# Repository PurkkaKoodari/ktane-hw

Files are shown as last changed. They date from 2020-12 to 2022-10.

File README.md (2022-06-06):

# KTaNE HW

This project is a hardware reimplementation of the game [Keep Talking and Nobody Explodes][ktane]. The game runs fully on the physical device and is controlled using a web interface over Wi-Fi. The project will be documented in this repository &ndash; expect the links below to be broken for the near future.

(TODO: insert photos here)

## Architecture

The hardware is built around a Raspberry Pi Zero W, which runs the main controller software, attached to a [backplane](doc/hardware/backplane.md) that provides power, connectivity and audio. The game's [modules](doc/hardware/modules.md) are built as independent devices, usually based on an Arduino Nano, which connect to the backplane using RJ-45 connectors (with a completely nonstandard usage of the pins).

The software can be divided into three parts: the [main controller](doc/software/main_controller.md), written in Python 3 using `asyncio` and [`websockets`][websockets]; the module software, written in C++ and built using [`arduino-cli`][arduino-cli]; and the Web interface, written using [Preact][preact]. In addition, one can run a [room server](doc/software/room_server.md), which supports room-scale audio and DMX lights and other effects.

## License

Unless otherwise noted, all software in this repository is licensed under the [MIT license](LICENSE); the hardware design files in `hardware/` are licensed under the [CERN-OHL-P v2](hardware/LICENSE); and the sounds in `sounds/` are licensed under CC-BY 3.0 (see [sounds/CREDITS.txt](sounds/CREDITS.txt) for authors).

This project is not in any way related to or endorsed by Steel Crate Games, nor does it include any assets from the original game. If you intend to build a copy of the project, please support them and [purchase a copy of the game][buy-ktane]!

[ktane]: http://www.keeptalkinggame.com/
[buy-ktane]: https://keeptalkinggame.com/#buynow
[websockets]: https://websockets.readthedocs.io/en/stable/intro.html
[arduino-cli]: https://arduino.github.io/arduino-cli/latest/commands/arduino-cli/
[preact]: https://preactjs.com/

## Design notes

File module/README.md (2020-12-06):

# Module firmware

## Libraries

- [Arduino-MCP2515][mcp2515] for CAN communication
- [Adafruit_LED_Backpack][ledbackpack] for modules using the HT16K33 chip
- [Custom library][ht1632c_bitbang] for modules using the HT1632C chip (see the [README.md][ht1632c_readme])
- [LiquidCrystal_I2C][lcd_i2c] for modules using 1602 LCDs with a PCF8574
- [FastLED][fastled] for modules using WS2812B (NeoPixel) LEDs

## Building

Building from command line using the included script is highly recommended.

Install [arduino-cli] first, then run `python3 build.py`.

Substitute your module details and serial port name.
Refer to `python3 build.py --help` for other options.

```sh
python3 build.py <module> <hwver> <serial> -u /dev/<serialport>
```

[arduino-cli]: https://arduino.github.io/arduino-cli/latest/installation/
[mcp2515]: https://github.com/autowp/arduino-mcp2515
[ht1632c_bitbang]: ../arduino-libraries/ht1632c_bitbang
[ht1632c_readme]: ../arduino-libraries/ht1632c_bitbang/README.md
[ledbackpack]: https://github.com/adafruit/Adafruit_LED_Backpack/
[lcd_i2c]: https://github.com/johnrickman/LiquidCrystal_I2C
[fastled]: https://github.com/FastLED/FastLED

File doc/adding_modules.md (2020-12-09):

# Adding modules

This document provides a step-by-step guide to adding new modules to the system.

## Conventions

### Version numbering

Each module has two version numbers, the hardware and software version, each represented as `major.minor`.

- The first released version is always 1.0.
- **Hardware version:**
    - The hardware version should always match the one printed on the board's silkscreen.
    - Any pre-release hardware should be marked as version 1.0 so that it can become the 1.0 release when it works.
    - A **major** version change indicates a major redesign that requires large firmware changes (e.g. changing of full mechanism).
    - A **minor** change may be anything smaller. It may still require changes in the firmware or main controller actions (e.g. pin changes, changing a driver chip, fixing errors that needed workarounds) or it may be a non-functional board update.
- **Software version:**
    - The software version is not tied to the hardware version, but relates to the bus protocol versioning.
    - Pre-release software may opt to use version 0.x or 1.0.
    - A **major** version change indicates that the main controller software will need a explicit update to support the protocol used by this version.
    - A **minor** version change indicates that the main controller may support this version without an explicit update. It may still be unable to use some new features in this version.

### Module IDs

You'll need a unique module ID. IDs 1-63 are reserved for vanilla modules, IDs 64-4095 for modded modules. Choose the lowest free ID from the appropriate range and add it in `bus_protocol.md`.

## 1. Build the hardware

A module starts with hardware. Most modules consist of the following:

- Faceplate, 100mm x 110mm x 3mm (WxHxD), acrylic/aluminum
    - 5mm on top/bottom reserved for mounting
    - All measurements below are from the 100mm x 100mm area excluding the mounting part
- PCB, usually 100mm x 100mm
    - 100mm x 100mm chosen for easy & cheap production
- Arduino-compatible microprocessor
    - Current modules use an Arduino Nano (or clone) on headers
- MCP2515 based CAN module with 5V bus voltage
    - Current modules use a MCP2515+TJA1050 module on headers, commonly available from China
- 10mm RGB LED for non-needy modules, centered 8mm from the right and top edges
- Mounting holes with M3 bolts
    - Usually centered 5mm from each edge, can be customized depending on module
    - With the RGB LED, the standard location for the top-right hole is 20mm from the right edge
- Various electrical, 3D-printed, laser-cut, etc. parts for the user interface

(TODO: add CAD models to repository for reference)

Before designing a new PCB, see if the [base module PCB][base-pcb] is enough for your needs. It breaks out many pins of the Arduino, including PWM and I&sup2;C and adds pins for two common LED matrix drivers, the HT1632C and HT16K33. It can be used as-is or by adding an adapter board. If you decide you need your own board, the base PCB is a good starting point as well.

Most module electronics should work with 5V. The MODULE_READY and MODULE_ENABLE signals, as well as the CAN bus, are configured for 5V operation. If your components need 3.3V, the module will need its own regulator.

The module connector additionally provides a 12V pin that can be used for more power-hungry peripherals such as motors or solenoids. This pin is not strictly 12V, but is intended to be the unregulated battery voltage &mdash; it may be anything from 11V to 15V, so make sure your components can handle that. Some bomb casings may not provide 12V power at all, as most modules don't use it.

## 2. Build the module firmware

The Arduino-based firmware needs to be extended to support your module.

1. Add your module ID to the start of `module.h`. This is the only change you'll need to make to existing files.
2. Copy [`newmodule.h`][newmodule.h] and [`newmodule.cpp`][newmodule.cpp] to the `module` directory and write your code as described in the comments.
3. Follow the instructions in [`module/README.md`][module-readme] to configure your build.

## 3. Add support in the controller software

The main controller then needs to be extended.

1. Copy [`template.py`][template.py] to your module's name (in lowercase) and write your code as described in the comments.
2. Add the name of your module to `bombgame/modules/__init__.py` so it will be loaded properly.
3. Optionally, write tests for your module. <!-- TODO: create a standard location - probably bombgame/test/modules -->

## 4. Add support in the frontend

The frontend is going to be rewritten soon, instructions will be updated later.

[base-pcb]: ../hardware/module_base
[newmodule.h]: ../module/module_template/newmodule.h
[newmodule.cpp]: ../module/module_template/newmodule.cpp
[template.py]: ../maincontroller/bombgame/modules/template.py
[module-readme]: ../module/README.md

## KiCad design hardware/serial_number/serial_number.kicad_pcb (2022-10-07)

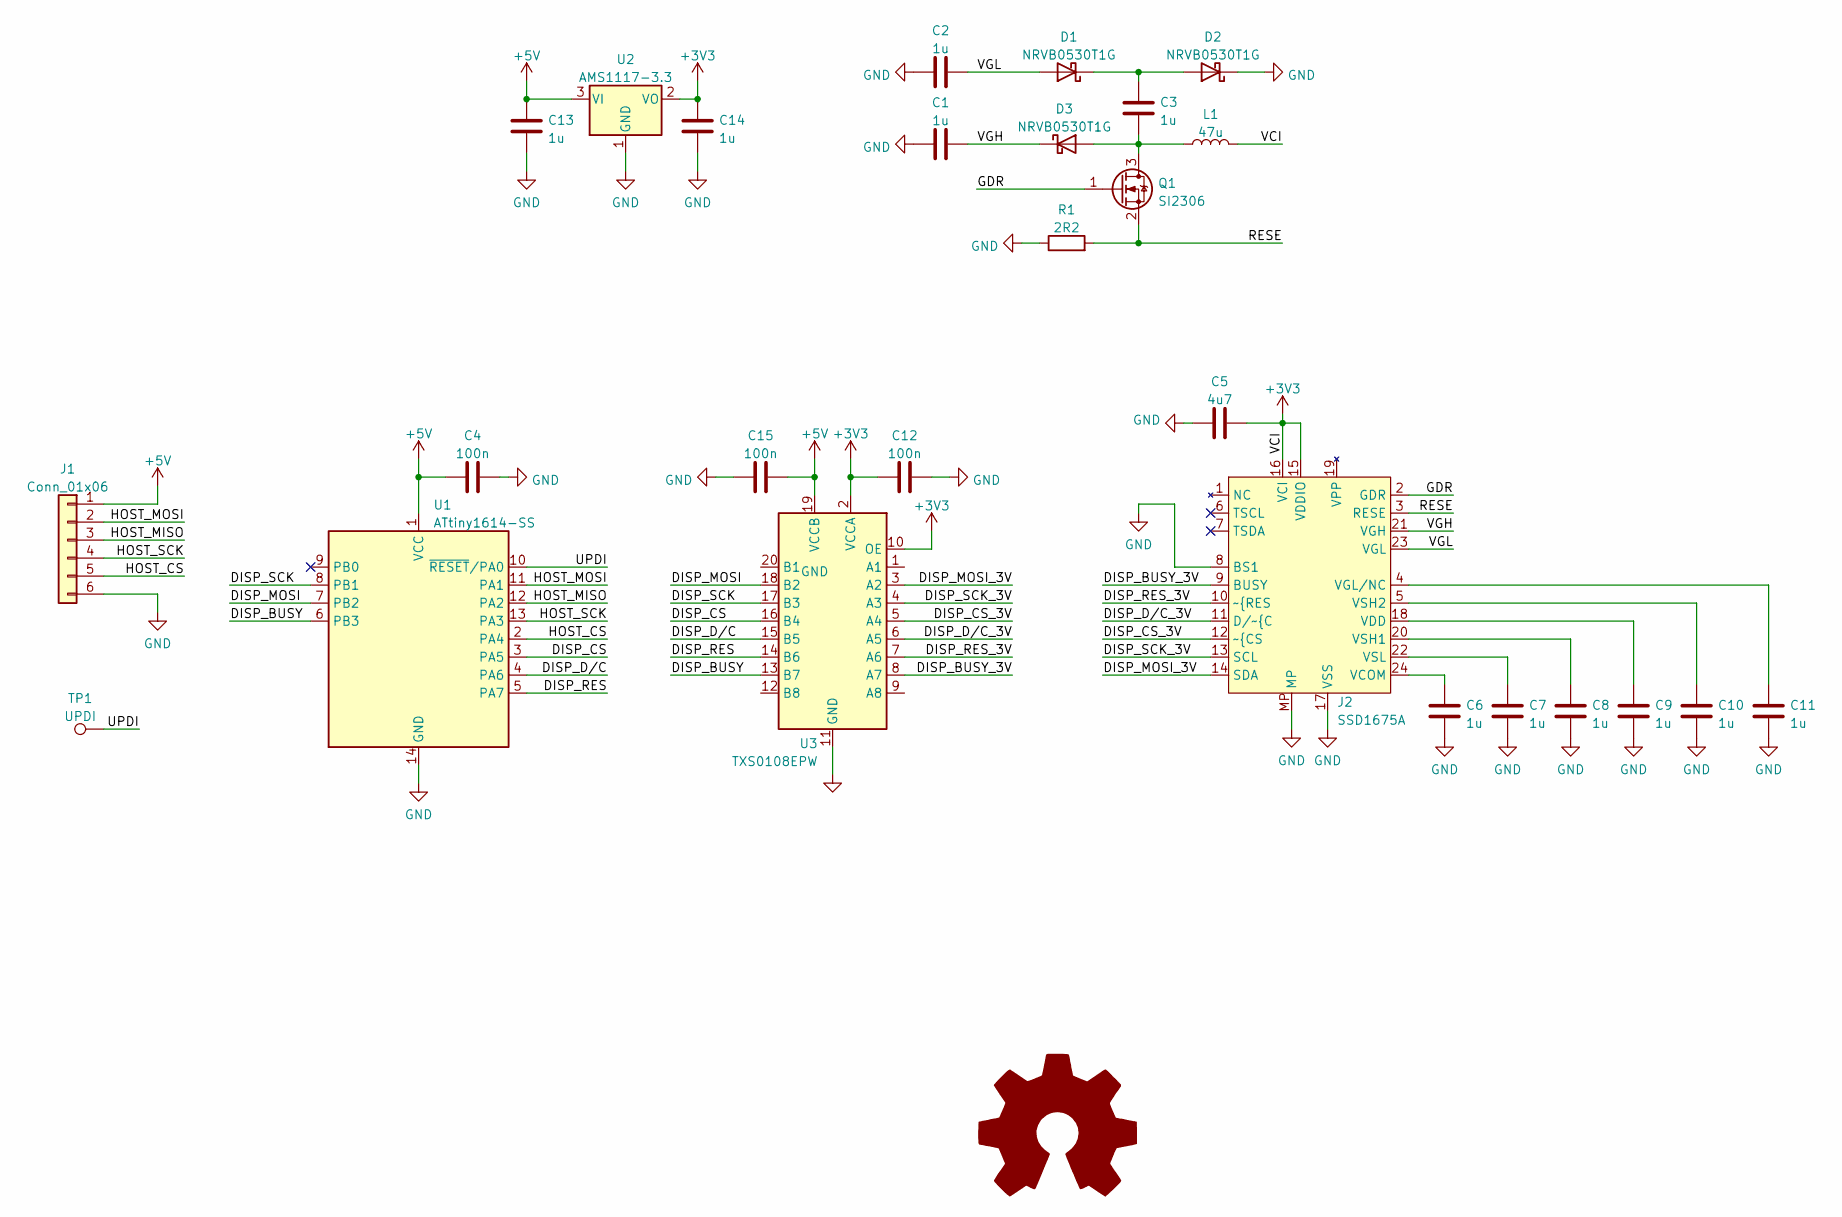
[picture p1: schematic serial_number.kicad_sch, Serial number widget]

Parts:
C1, C2, C3, C6, C7, C8, C9, C10, C11, C13, C14: 1u; C_0603_1608Metric_Pad1.08x0.95mm
C4, C12, C15: 100n; C_0603_1608Metric_Pad1.08x0.95mm
C5: 4u7; C_0603_1608Metric_Pad1.08x0.95mm
D1, D2, D3: NRVB0530T1G; D_SOD-123
J1: Conn_01x06; PinHeader_1x06_P2.54mm_Vertical
J2: SSD1675A; ER-CON24HT-1
L1: 47u; L_Taiyo-Yuden_NR-40xx
LOGO1: Logo_Open_Hardware_Large; OSHW-Logo_11.4x12mm_SilkScreen
Q1: SI2306; SOT-23_Handsoldering
R1: 2R2; R_0805_2012Metric_Pad1.20x1.40mm
TP1: UPDI; TestPoint_Pad_D2.5mm
U1: ATtiny1614-SS; SOIC-14_3.9x8.7mm_P1.27mm
U2: AMS1117-3.3; SOT-223-3_TabPin2
U3: TXS0108EPW; TSSOP-20_4.4x6.5mm_P0.65mm

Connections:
+3V3: C5.2, C12.1, C14.2, J2.15 (VDDIO), J2.16 (VCI), L1.2, U2.2 (VO), U3.2 (VCCA), U3.10 (OE)
+5V: C4.1, C13.2, C15.1, J1.1, U1.1 (VCC), U2.3 (VI), U3.19 (VCCB)
/DISP_BUSY: U1.6 (PB3), U3.13 (B7)
/DISP_BUSY_3V: J2.9 (BUSY), U3.8 (A7)
/DISP_CS: U1.3 (PA5), U3.16 (B4)
/DISP_CS_3V: J2.12 (~{CS), U3.5 (A4)
/DISP_D/C: U1.4 (PA6), U3.15 (B5)
/DISP_D/C_3V: J2.11 (D/~{C), U3.6 (A5)
/DISP_MOSI: U1.7 (PB2), U3.18 (B2)
/DISP_MOSI_3V: J2.14 (SDA), U3.3 (A2)
/DISP_RES: U1.5 (PA7), U3.14 (B6)
/DISP_RES_3V: J2.10 (~{RES), U3.7 (A6)
/DISP_SCK: U1.8 (PB1), U3.17 (B3)
/DISP_SCK_3V: J2.13 (SCL), U3.4 (A3)
/GDR: J2.2 (GDR), Q1.1 (G)
/HOST_CS: J1.5, U1.2 (PA4)
/HOST_MISO: J1.3, U1.12 (PA2)
/HOST_MOSI: J1.2, U1.11 (PA1)
/HOST_SCK: J1.4, U1.13 (PA3)
/RESE: J2.3 (RESE), Q1.2 (S), R1.2
/UPDI: TP1.1, U1.10 (~RESET/PA0)
/VGH: C1.2, D3.1 (K), J2.21 (VGH)
/VGL: C2.2, D1.2 (A), J2.23 (VGL)
GND: C1.1, C2.1, C4.2, C5.1, C6.1, C7.1, C8.1, C9.1, C10.1, C11.1, C12.2, C13.1, C14.1, C15.2, D2.1 (K), J1.6, J2.8 (BS1), J2.17 (VSS), J2.MP, R1.1, U1.14 (GND), U2.1 (GND), U3.11 (GND)
unnamed: C3.1, D1.1 (K), D2.2 (A)
unnamed: C3.2, D3.2 (A), L1.1, Q1.3 (D)
unnamed: C6.2, J2.24 (VCOM)
unnamed: C7.2, J2.22 (VSL)
unnamed: C8.2, J2.20 (VSH1)
unnamed: C9.2, J2.18 (VDD)
unnamed: C10.2, J2.5 (VSH2)
unnamed: C11.2, J2.4 (VGL/NC)

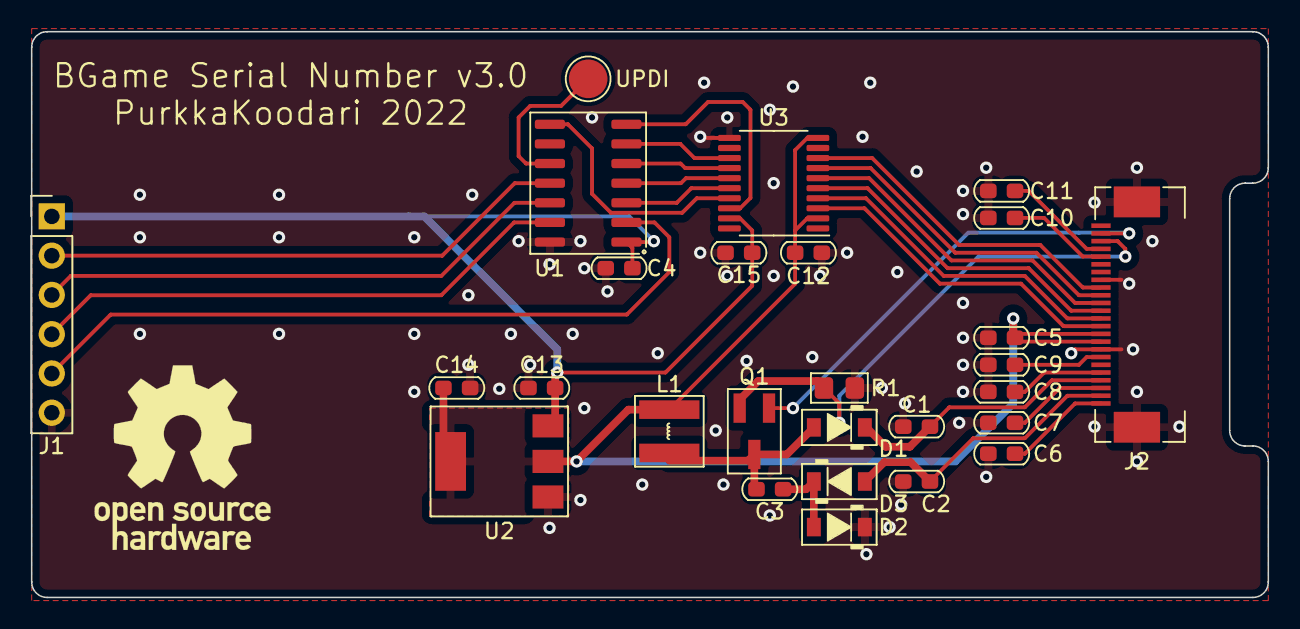
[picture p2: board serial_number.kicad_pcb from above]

Board: 2 copper layers, 80.0 x 36.6 mm, 28 parts (0 on the bottom side), 32 nets.

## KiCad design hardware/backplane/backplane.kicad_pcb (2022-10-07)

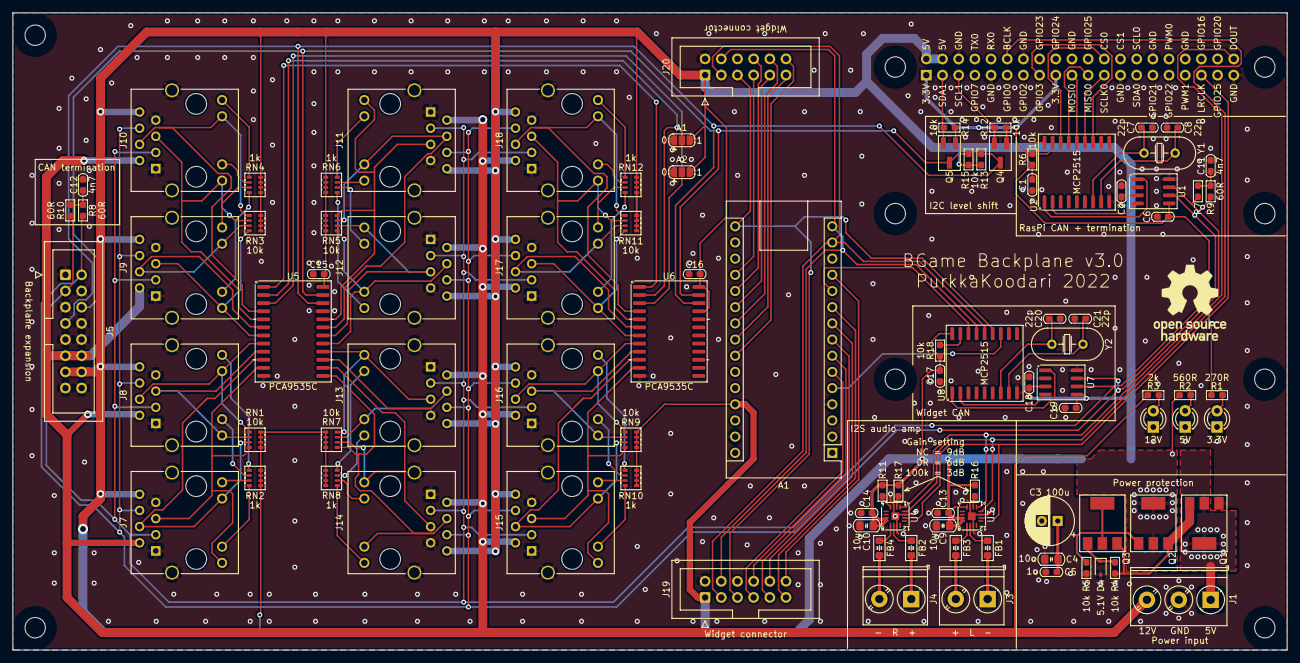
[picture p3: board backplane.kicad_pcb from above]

Board: 2 copper layers, 200.0 x 100.0 mm, 103 parts (1 on the bottom side), 116 nets.

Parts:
A1: Arduino_Nano_v3.x; Arduino_Nano
C1, C2, C6, C13, C14, C15, C16, C17, C18, C19: 100n; C_0603_1608Metric_Pad1.08x0.95mm
C3: 100u; CP_Radial_D7.5mm_P2.50mm
C4, C9, C10: 10u; C_0805_2012Metric_Pad1.18x1.45mm
C5: 1u; C_0603_1608Metric_Pad1.08x0.95mm
C7, C8, C20, C21: 22p; C_0603_1608Metric_Pad1.08x0.95mm
C11, C12: 4n7; C_0603_1608Metric_Pad1.08x0.95mm
D1, D2, D3: LED; LED_D3.0mm
D4: BZX384-5V1; D_SOD-323
FB1, FB2, FB3, FB4: Ferrite_Bead; Ferrite_0805_2012Metric_Pad1.05x1.20mm_BigPads
H_RPI1, H_RPI2: RPi_HDR; MountingHole_3.2mm_M3
H_RPI3, H_RPI4: RPi_ZERO; MountingHole_3.2mm_M3
H_RPI5, H_RPI6: RPi_3; MountingHole_3.2mm_M3
J1: Screw_Terminal_01x03; TerminalBlock_Phoenix_PT-1,5-3-5.0-H_1x03_P5.00mm_Horizontal
J2: Raspberry_Pi_2_3; PinSocket_2x20_P2.54mm_Vertical
J3, J4: Screw_Terminal_01x02; TerminalBlock_Phoenix_PT-1,5-2-5.0-H_1x02_P5.00mm_Horizontal
J5: Conn_02x08_Odd_Even; IDC-Header_2x08_P2.54mm_Vertical
J7, J8, J9, J10, J11, J12, J13, J14, J15, J16, J17, J18: RJ45_LED_Shielded; RJ45_RCH5242CB
J19, J20: Conn_02x06_Odd_Even; IDC-Header_2x06_P2.54mm_Vertical
JP1: GPIO_A1; SolderJumper-3_P1.3mm_Open_RoundedPad1.0x1.5mm
JP2: GPIO_A2; SolderJumper-3_P1.3mm_Open_RoundedPad1.0x1.5mm
LOGO1: Logo_Open_Hardware_Small; OSHW-Logo_11.4x12mm_SilkScreen
Q1, Q2, Q3: ZXMP4A16G; SOT-223-3_TabPin2
Q4, Q5: Q_NMOS_GSD; SOT-23_Handsoldering
R1: 270R; R_0603_1608Metric_Pad1.05x0.95mm
R2: 560R; R_0603_1608Metric_Pad1.05x0.95mm
R3: 2k; R_0603_1608Metric_Pad1.05x0.95mm
R4, R5, R6, R12, R13, R14, R15, R18: 10k; R_0603_1608Metric_Pad1.05x0.95mm
R7, R8, R9, R10: 60R; R_0603_1608Metric_Pad1.05x0.95mm
R11: 330k; R_0603_1608Metric_Pad1.05x0.95mm
R16, R17: 100k; R_0603_1608Metric_Pad1.05x0.95mm
RN1, RN3, RN5, RN7, RN9, RN11: 10k; R_Array_Convex_4x0603
RN2, RN4, RN6, RN8, RN10, RN12: 1k; R_Array_Convex_4x0603
U1, U7: TJA1051T/3; SOIC-8_3.9x4.9mm_P1.27mm
U2, U8: MCP2515-xSO; SOIC-18W_7.5x11.6mm_P1.27mm
U3, U4: MAX98357AETE; TQFN-16-1EP_3x3mm_P0.5mm_EP1.23x1.23mm
U5, U6: PCA9535C; SOIC-24W_7.5x15.4mm_P1.27mm
Y1, Y2: 8MHz; Crystal_HC49-U_Vertical

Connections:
+3V3: C1.1, C6.1, J2.1 (3V3), J2.17 (3V3), Q4.1 (G), Q5.1 (G), R1.1, R6.1, R12.1, R14.1, U1.5 (VIO), U2.18 (VDD)
+5V: J1.1, Q1.2 (D)
+12V: J1.3, J5.11, J5.12, J7.2, J8.2, J9.2, J10.2, J11.2, J12.2, J13.2, J14.2, J15.2, J16.2, J17.2, J18.2, R3.1
/CAN_CS: J2.24 (~CE0/GPIO8), U2.16 (~CS)
/CAN_INT: J2.15 (GPIO22), U2.12 (~INT)
/GPIO_ADDR1: JP1.2 (C), U5.2 (A1), U6.2 (A1)
/GPIO_ADDR2: JP2.2 (C), U5.3 (A2), U6.3 (A2)
/GPIO_INT: U5.1 (~INT), U6.1 (~INT)
/MISO_3V3: J2.21 (MISO0/GPIO9), U2.15 (SO)
/MODULE_LOCATE_0: J7.4, J7.11, RN1.7 (R2.2), U5.10 (IO0_6)
/MODULE_LOCATE_1: J8.4, J8.11, RN1.5 (R4.2), U5.8 (IO0_4)
/MODULE_LOCATE_2: J9.4, J9.11, RN3.7 (R2.2), U5.6 (IO0_2)
/MODULE_LOCATE_3: J10.4, J10.11, RN3.5 (R4.2), U5.4 (IO0_0)
/MODULE_LOCATE_4: J11.4, J11.11, RN5.7 (R2.2), U5.19 (IO1_6)
/MODULE_LOCATE_5: J12.4, J12.11, RN5.5 (R4.2), U5.17 (IO1_4)
/MODULE_LOCATE_6: J13.4, J13.11, RN7.7 (R2.2), U5.15 (IO1_2)
/MODULE_LOCATE_7: J14.4, J14.11, RN7.5 (R4.2), U5.13 (IO1_0)
/MODULE_LOCATE_8: J15.4, J15.11, RN9.7 (R2.2), U6.10 (IO0_6)
/MODULE_LOCATE_9: J16.4, J16.11, RN9.5 (R4.2), U6.8 (IO0_4)
/MODULE_LOCATE_10: J17.4, J17.11, RN11.7 (R2.2), U6.6 (IO0_2)
/MODULE_LOCATE_11: J18.4, J18.11, RN11.5 (R4.2), U6.4 (IO0_0)
/MODULE_SENSE_0: J7.5, J7.9, RN1.8 (R1.2), U5.11 (IO0_7)
/MODULE_SENSE_1: J8.5, J8.9, RN1.6 (R3.2), U5.9 (IO0_5)
/MODULE_SENSE_2: J9.5, J9.9, RN3.8 (R1.2), U5.7 (IO0_3)
/MODULE_SENSE_3: J10.5, J10.9, RN3.6 (R3.2), U5.5 (IO0_1)
/MODULE_SENSE_4: J11.5, J11.9, RN5.8 (R1.2), U5.20 (IO1_7)
/MODULE_SENSE_5: J12.5, J12.9, RN5.6 (R3.2), U5.18 (IO1_5)
/MODULE_SENSE_6: J13.5, J13.9, RN7.8 (R1.2), U5.16 (IO1_3)
/MODULE_SENSE_7: J14.5, J14.9, RN7.6 (R3.2), U5.14 (IO1_1)
/MODULE_SENSE_8: J15.5, J15.9, RN9.8 (R1.2), U6.11 (IO0_7)
/MODULE_SENSE_9: J16.5, J16.9, RN9.6 (R3.2), U6.9 (IO0_5)
/MODULE_SENSE_10: J17.5, J17.9, RN11.8 (R1.2), U6.7 (IO0_3)
/MODULE_SENSE_11: J18.5, J18.9, RN11.6 (R3.2), U6.5 (IO0_1)
/MOSI_3V3: J2.19 (MOSI0/GPIO10), U2.14 (SI)
/PCM_BCLK: J2.12 (GPIO18/PWM0), U3.16 (BCLK), U4.16 (BCLK)
/PCM_DOUT: J2.40 (GPIO21/SCLK1), U3.1 (DIN), U4.1 (DIN)
/PCM_LRCLK: J2.35 (GPIO19/MISO1), U3.14 (LRCLK), U4.14 (LRCLK)
/SCL: J5.7, Q4.3 (D), R13.2, U5.22 (SCL), U6.22 (SCL)
/SCLK_3V3: J2.23 (SCLK0/GPIO11), U2.13 (SCK)
/SCL_3V3: J2.5 (SCL/GPIO3), Q4.2 (S), R12.2
/SDA: J5.6, Q5.3 (D), R15.2, U5.23 (SDA), U6.23 (SDA)
/SDA_3V3: J2.3 (SDA/GPIO2), Q5.2 (S), R14.2
/SPKR_L+: FB3.2, J3.2
/SPKR_L-: FB1.2, J3.1
/SPKR_R+: FB4.2, J4.2
/SPKR_R-: FB2.2, J4.1
/WIDGET_CAN_CS: A1.11 (D8), U8.16 (~CS)
/WIDGET_CAN_INT: A1.5 (D2), U8.12 (~INT)
/WIDGET_CS0: A1.6 (D3), J19.7
/WIDGET_CS1: A1.7 (D4), J19.8
/WIDGET_CS2: A1.8 (D5), J19.9
/WIDGET_CS3: A1.9 (D6), J19.10
/WIDGET_CS4: A1.10 (D7), J19.11
/WIDGET_CS5: A1.12 (D9), J19.12
/WIDGET_CS6: A1.19 (A0), J20.7
/WIDGET_CS7: A1.20 (A1), J20.8
/WIDGET_CS8: A1.21 (A2), J20.9
/WIDGET_CS9: A1.22 (A3), J20.10
/WIDGET_CS10: A1.23 (A4), J20.11
/WIDGET_CS11: A1.24 (A5), J20.12
/WIDGET_MISO: A1.15 (D12), J19.4, J20.4, U8.15 (SO)
/WIDGET_MOSI: A1.14 (D11), J19.3, J20.3, U8.14 (SI)
/WIDGET_SCLK: A1.16 (D13), J19.5, J20.5, U8.13 (SCK)
CAN_H: J5.2, J7.6, J8.6, J9.6, J10.6, J11.6, J12.6, J13.6, J14.6, J15.6, J16.6, J17.6, J18.6, R7.1, R8.1, U1.7 (CANH), U7.7 (CANH)
CAN_L: J5.3, J7.3, J8.3, J9.3, J10.3, J11.3, J12.3, J13.3, J14.3, J15.3, J16.3, J17.3, J18.3, R9.1, R10.1, U1.6 (CANL), U7.6 (CANL)
GND: A1.4 (GND), A1.29 (GND), C1.2, C2.2, C3.2, C4.2, C5.2, C6.2, C7.2, C8.2, C9.1, C10.1, C11.2, C12.2, C13.1, C14.1, C15.2, C16.2, C17.2, C18.2, C19.2, C20.2, C21.2, D1.1 (K), D2.1 (K), D3.1 (K), D4.2 (A), J1.2, J2.6 (GND), J2.9 (GND), J2.14 (GND), J2.20 (GND), J2.25 (GND), J2.30 (GND), J2.34 (GND), J2.39 (GND), J5.1, J5.4, J5.5, J5.8, J5.9, J5.10, J5.15, J5.16, J7.1, J7.7, J7.SH, J8.1, J8.7, J8.SH, J9.1, J9.7, J9.SH, J10.1, J10.7, J10.SH, J11.1, J11.7, J11.SH, J12.1, J12.7, J12.SH, J13.1, J13.7, J13.SH, J14.1, J14.7, J14.SH, J15.1, J15.7, J15.SH, J16.1, J16.7, J16.SH, J17.1, J17.7, J17.SH, J18.1, J18.7, J18.SH, J19.2, J20.2, JP1.1 (A), JP2.1 (A), Q1.1 (G), R5.2, U1.2 (GND), U1.8 (S), U2.9 (VSS), U3.3 (GND), U3.11 (GND), U3.15 (GND), U3.17 (EP), U4.3 (GND), U4.11 (GND), U4.15 (GND), U4.17 (EP), U5.12 (VSS), U5.21 (A0), U6.12 (VSS), U7.2 (GND), U7.8 (S), U8.9 (VSS)
unnamed: C7.1, U2.7 (OSC2), Y1.1
unnamed: C8.1, U2.8 (OSC1), Y1.2
unnamed: C11.1, R7.2, R9.2
unnamed: C12.1, R8.2, R10.2
unnamed: C20.1, U8.7 (OSC2), Y2.1
unnamed: C21.1, U8.8 (OSC1), Y2.2
unnamed: D1.2 (A), R1.2
unnamed: D2.2 (A), R2.2
unnamed: D3.2 (A), R3.2
unnamed: D4.1 (K), Q3.1 (G), R4.2
unnamed: FB1.1, U3.10 (OUTN)
unnamed: FB2.1, U4.10 (OUTN)
unnamed: FB3.1, U3.9 (OUTP)
unnamed: FB4.1, U4.9 (OUTP)
unnamed: J7.10, RN2.8 (R1.2)
unnamed: J7.12, RN2.7 (R2.2)
unnamed: J8.10, RN2.6 (R3.2)
unnamed: J8.12, RN2.5 (R4.2)
unnamed: J9.10, RN4.8 (R1.2)
unnamed: J9.12, RN4.7 (R2.2)
unnamed: J10.10, RN4.6 (R3.2)
unnamed: J10.12, RN4.5 (R4.2)
unnamed: J11.10, RN6.8 (R1.2)
unnamed: J11.12, RN6.7 (R2.2)
unnamed: J12.10, RN6.6 (R3.2)
unnamed: J12.12, RN6.5 (R4.2)
unnamed: J13.10, RN8.8 (R1.2)
unnamed: J13.12, RN8.7 (R2.2)
unnamed: J14.10, RN8.6 (R3.2)
unnamed: J14.12, RN8.5 (R4.2)
unnamed: J15.10, RN10.8 (R1.2)
unnamed: J15.12, RN10.7 (R2.2)
unnamed: J16.10, RN10.6 (R3.2)
unnamed: J16.12, RN10.5 (R4.2)
unnamed: J17.10, RN12.8 (R1.2)
unnamed: J17.12, RN12.7 (R2.2)
unnamed: J18.10, RN12.6 (R3.2)
unnamed: J18.12, RN12.5 (R4.2)
unnamed: Q1.3 (S), Q2.3 (S), Q3.3 (S), R4.1
unnamed: Q2.1 (G), Q3.2 (D), R5.1
unnamed: R6.2, U2.17 (~RESET)
unnamed: R11.2, U4.4 (~SD_MODE)
unnamed: R16.2, U3.2 (GAIN_SLOT)
unnamed: R17.2, U4.2 (GAIN_SLOT)
unnamed: R18.2, U8.17 (~RESET)
unnamed: U1.1 (TXD), U2.1 (TXCAN)
unnamed: U1.4 (RXD), U2.2 (RXCAN)
unnamed: U7.1 (TXD), U8.1 (TXCAN)
unnamed: U7.4 (RXD), U8.2 (RXCAN)
VCC: A1.27 (+5V), C2.1, C3.1, C4.1, C5.1, C9.2, C10.2, C13.2, C14.2, C15.1, C16.1, C17.1, C18.1, C19.1, J2.2 (5V), J2.4 (5V), J5.13, J5.14, J7.8, J8.8, J9.8, J10.8, J11.8, J12.8, J13.8, J14.8, J15.8, J16.8, J17.8, J18.8, J19.1, J20.1, JP1.3 (B), JP2.3 (B), Q2.2 (D), R2.1, R11.1, R13.1, R15.1, R16.1, R17.1, R18.1, RN1.1 (R1.1), RN1.2 (R2.1), RN1.3 (R3.1), RN1.4 (R4.1), RN2.1 (R1.1), RN2.2 (R2.1), RN2.3 (R3.1), RN2.4 (R4.1), RN3.1 (R1.1), RN3.2 (R2.1), RN3.3 (R3.1), RN3.4 (R4.1), RN4.1 (R1.1), RN4.2 (R2.1), RN4.3 (R3.1), RN4.4 (R4.1), RN5.1 (R1.1), RN5.2 (R2.1), RN5.3 (R3.1), RN5.4 (R4.1), RN6.1 (R1.1), RN6.2 (R2.1), RN6.3 (R3.1), RN6.4 (R4.1), RN7.1 (R1.1), RN7.2 (R2.1), RN7.3 (R3.1), RN7.4 (R4.1), RN8.1 (R1.1), RN8.2 (R2.1), RN8.3 (R3.1), RN8.4 (R4.1), RN9.1 (R1.1), RN9.2 (R2.1), RN9.3 (R3.1), RN9.4 (R4.1), RN10.1 (R1.1), RN10.2 (R2.1), RN10.3 (R3.1), RN10.4 (R4.1), RN11.1 (R1.1), RN11.2 (R2.1), RN11.3 (R3.1), RN11.4 (R4.1), RN12.1 (R1.1), RN12.2 (R2.1), RN12.3 (R3.1), RN12.4 (R4.1), U1.3 (VCC), U3.4 (~SD_MODE), U3.7 (VDD), U3.8 (VDD), U4.7 (VDD), U4.8 (VDD), U5.24 (VDD), U6.21 (A0), U6.24 (VDD), U7.3 (VCC), U7.5 (VIO), U8.18 (VDD)

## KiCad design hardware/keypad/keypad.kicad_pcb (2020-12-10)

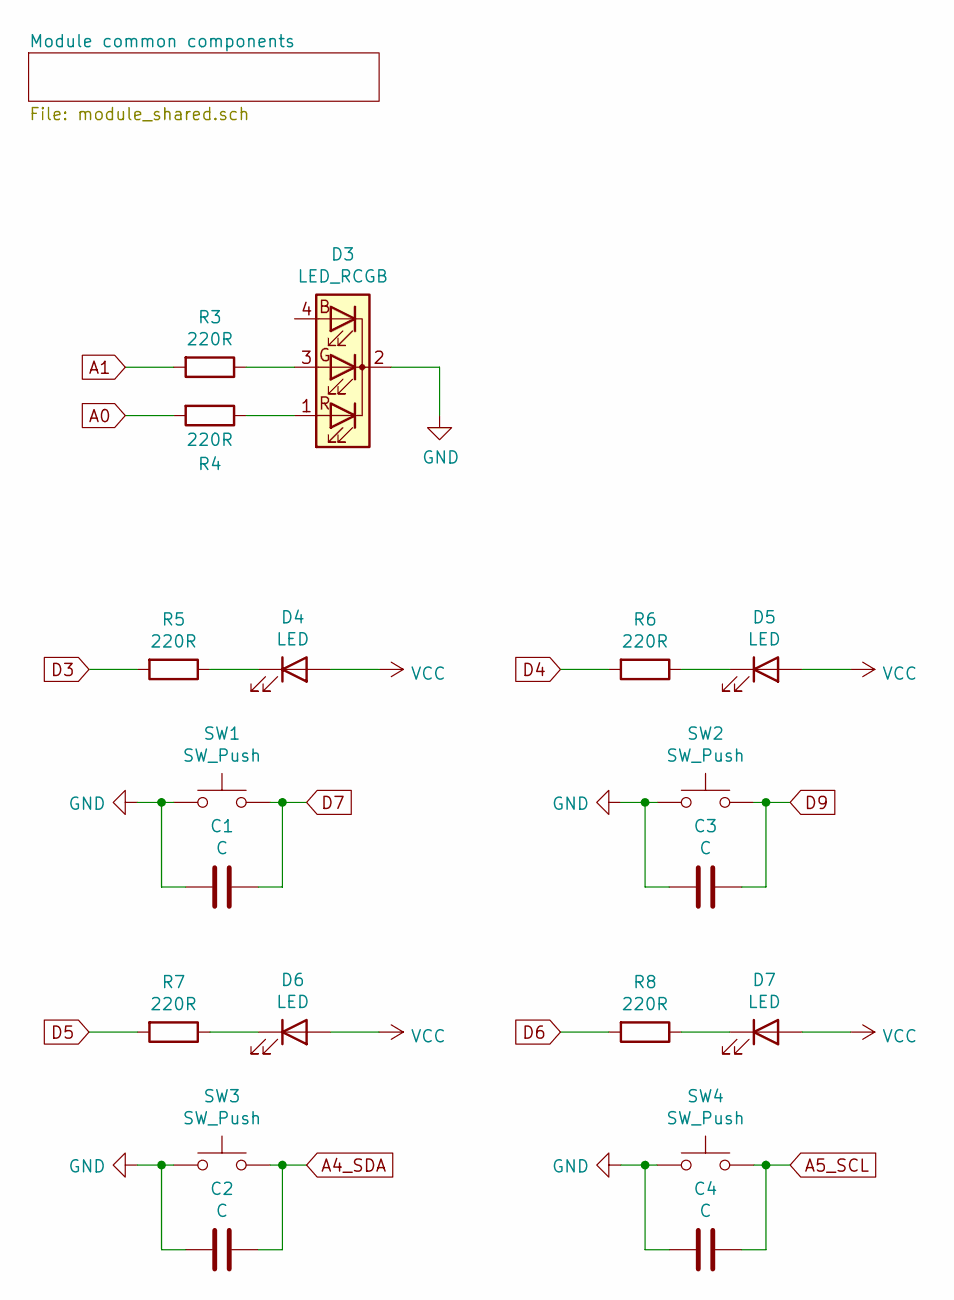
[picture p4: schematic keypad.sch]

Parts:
C1, C2, C3, C4: C; C_0805_2012Metric_Pad1.15x1.40mm_HandSolder
D3: LED_RCGB; LED_D5.0mm-4_RGB_Wide_Pins
D4, D5, D6, D7: LED; LED_D3.0mm
R3, R4, R5, R6, R7, R8: 220R; R_0603_1608Metric_Pad1.05x0.95mm_HandSolder
SW1, SW2, SW3, SW4: SW_Push; SW_Cherry_MX_1.00u_PCB

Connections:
A0: R4.2; also elsewhere on the board
A1: R3.2; also elsewhere on the board
A4_SDA: C2.1, SW3.2; also elsewhere on the board
A5_SCL: C4.1, SW4.2; also elsewhere on the board
D3: R5.2; also elsewhere on the board
D4: R6.2; also elsewhere on the board
D5: R7.2; also elsewhere on the board
D6: R8.2; also elsewhere on the board
D7: C1.1, SW1.2; also elsewhere on the board
D9: C3.1, SW2.2; also elsewhere on the board
GND: C1.2, C2.2, C3.2, C4.2, D3.2 (K), SW1.1, SW2.1, SW3.1, SW4.1; also elsewhere on the board
unnamed: D3.1 (RA), R4.1
unnamed: D3.3 (GA), R3.1
unnamed: D4.1 (K), R5.1
unnamed: D5.1 (K), R6.1
unnamed: D6.1 (K), R7.1
unnamed: D7.1 (K), R8.1
VCC: D4.2 (A), D5.2 (A), D6.2 (A), D7.2 (A); also elsewhere on the board

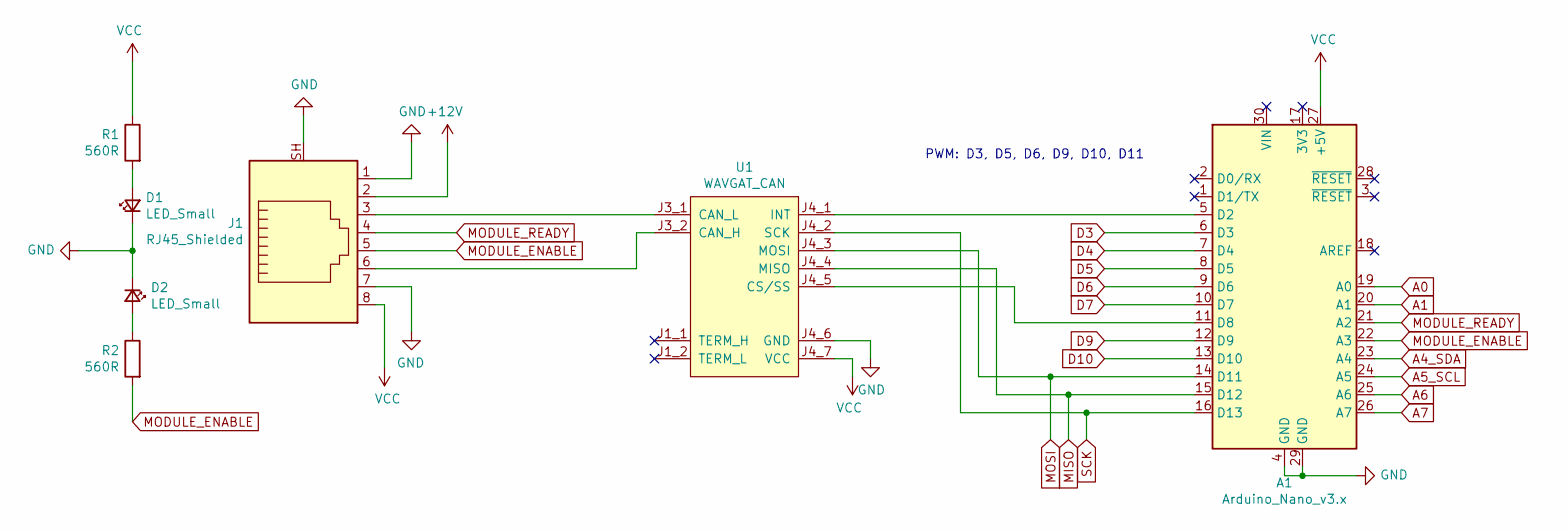
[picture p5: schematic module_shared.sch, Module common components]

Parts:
A1: Arduino_Nano_v3.x; Arduino_Nano
D1, D2: LED_Small; LED_D3.0mm
J1: RJ45_Shielded; RJ45_5224
R1, R2: 560R; R_0603_1608Metric_Pad1.05x0.95mm_HandSolder
U1: WAVGAT_CAN

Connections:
+12V: J1.2
A0: A1.19 (A0); also elsewhere on the board
A1: A1.20 (A1); also elsewhere on the board
A4_SDA: A1.23 (A4); also elsewhere on the board
A5_SCL: A1.24 (A5); also elsewhere on the board
A6: A1.25 (A6)
A7: A1.26 (A7)
D3: A1.6 (D3); also elsewhere on the board
D4: A1.7 (D4); also elsewhere on the board
D5: A1.8 (D5); also elsewhere on the board
D6: A1.9 (D6); also elsewhere on the board
D7: A1.10 (D7); also elsewhere on the board
D9: A1.12 (D9); also elsewhere on the board
D10: A1.13 (D10)
GND: A1.4 (GND), A1.29 (GND), D1.1 (K), D2.1 (K), J1.1, J1.7, J1.SH, U1.J4_6 (GND); also elsewhere on the board
MISO: A1.15 (D12), U1.J4_4 (MISO)
MODULE_ENABLE: A1.22 (A3), J1.5, R2.2
MODULE_READY: A1.21 (A2), J1.4
MOSI: A1.14 (D11), U1.J4_3 (MOSI)
unnamed: A1.5 (D2), U1.J4_1 (INT)
unnamed: A1.11 (D8), U1.J4_5 (CS/SS)
unnamed: D1.2 (A), R1.2
unnamed: D2.2 (A), R2.1
unnamed: J1.3, U1.J3_1 (CAN_L)
unnamed: J1.6, U1.J3_2 (CAN_H)
SCK: A1.16 (D13), U1.J4_2 (SCK)
VCC: A1.27 (+5V), J1.8, R1.1, U1.J4_7 (VCC); also elsewhere on the board

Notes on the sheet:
PWM: D3, D5, D6, D9, D10, D11

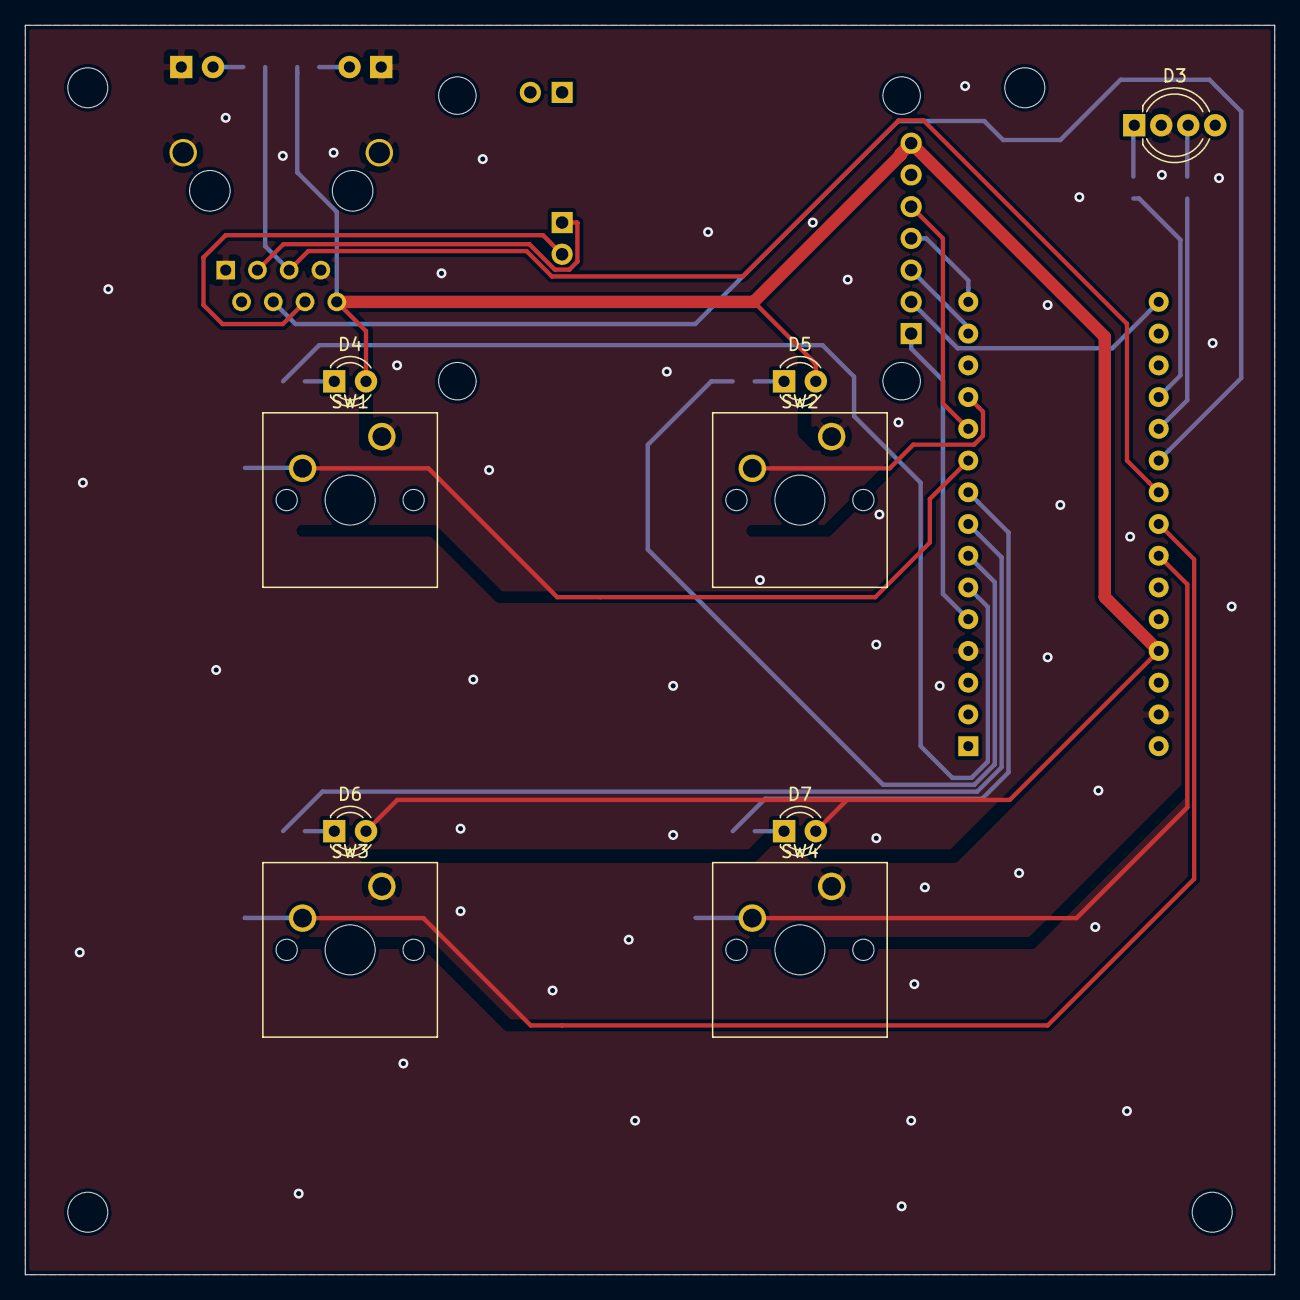
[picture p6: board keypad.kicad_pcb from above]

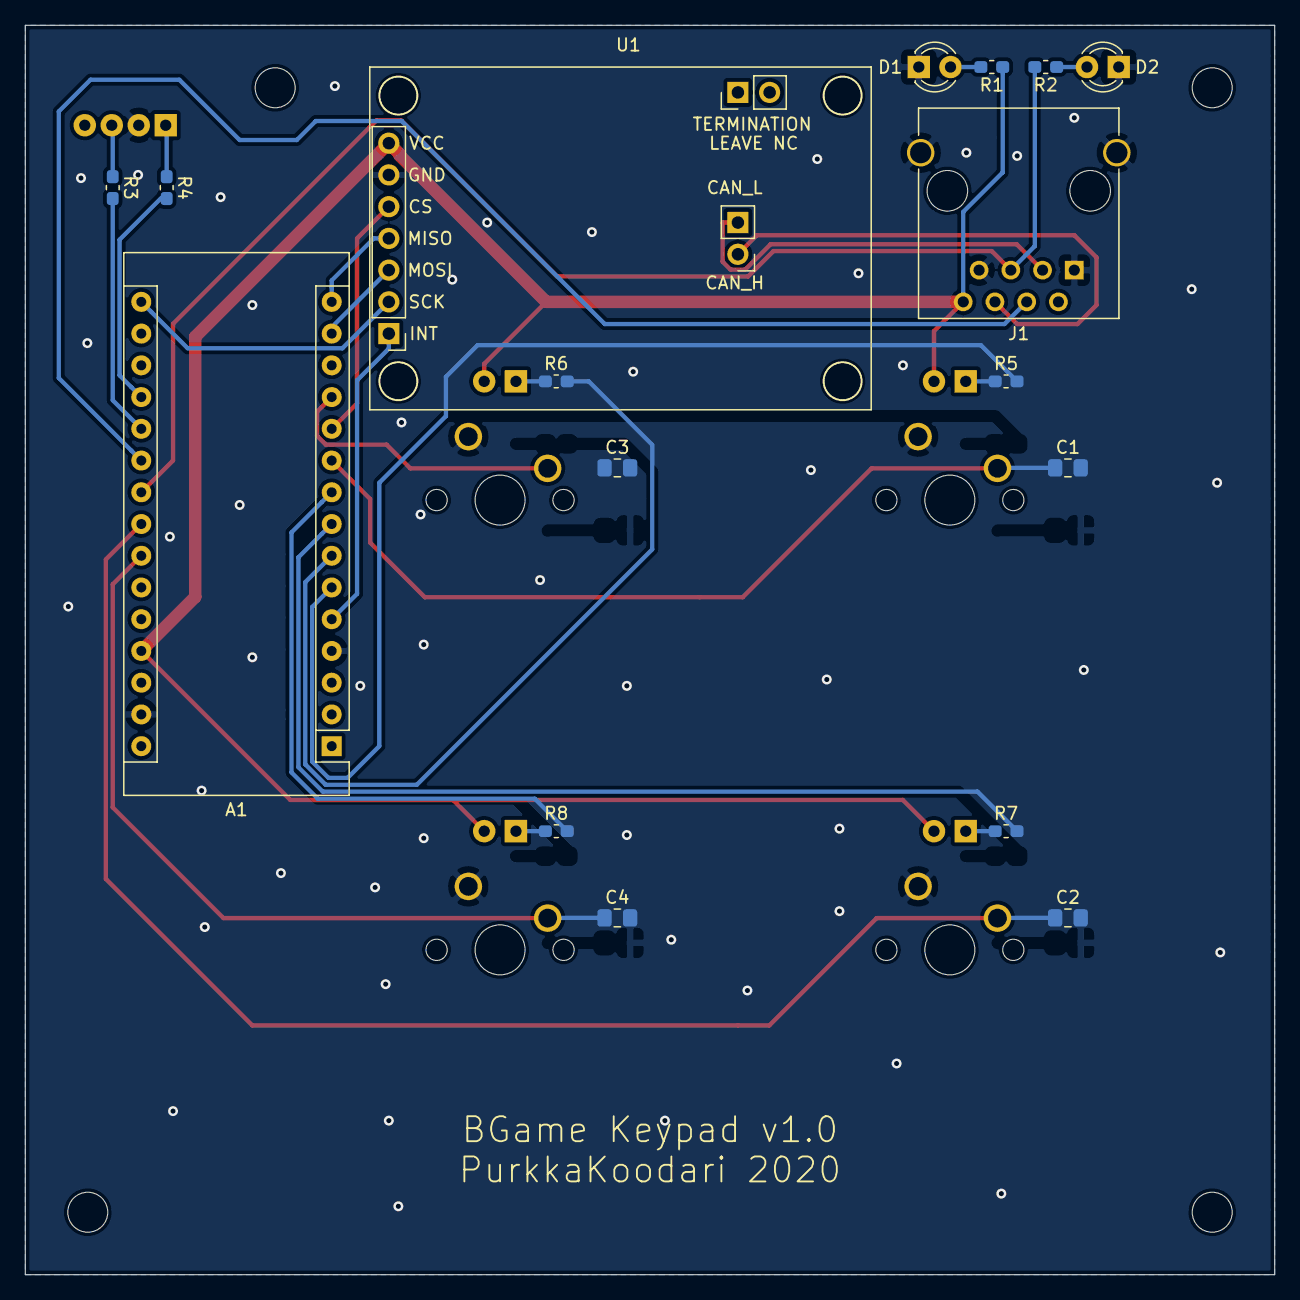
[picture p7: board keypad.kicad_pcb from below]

Board: 2 copper layers, 100.0 x 100.0 mm, 26 parts (17 on the bottom side), 29 nets.

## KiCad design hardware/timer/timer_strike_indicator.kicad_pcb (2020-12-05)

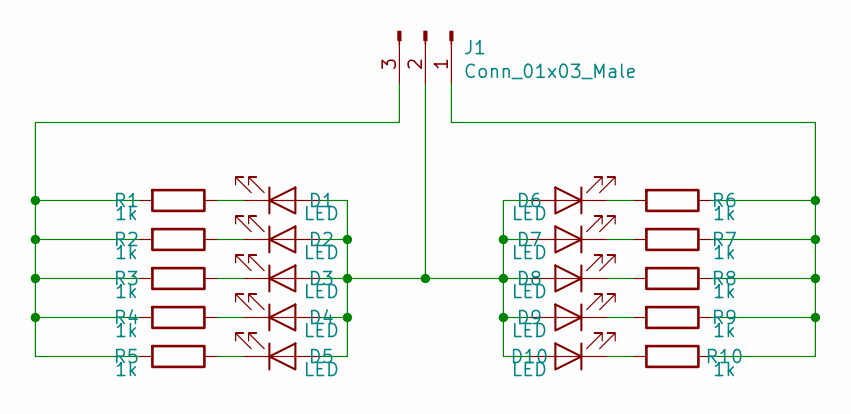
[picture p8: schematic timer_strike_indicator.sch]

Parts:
D1, D2, D3, D4, D5, D6, D7, D8, D9, D10: LED; LED_D3.0mm
J1: Conn_01x03_Male; PinHeader_1x03_P2.54mm_Vertical
R1, R2, R3, R4, R5, R6, R7, R8, R9, R10: 1k; R_0603_1608Metric_Pad1.05x0.95mm_HandSolder

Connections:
unnamed: D1.1 (K), R1.1
unnamed: D1.2 (A), D2.2 (A), D3.2 (A), D4.2 (A), D5.2 (A), D6.2 (A), D7.2 (A), D8.2 (A), D9.2 (A), D10.2 (A), J1.2
unnamed: D2.1 (K), R2.1
unnamed: D3.1 (K), R3.1
unnamed: D4.1 (K), R4.1
unnamed: D5.1 (K), R5.1
unnamed: D6.1 (K), R6.2
unnamed: D7.1 (K), R7.2
unnamed: D8.1 (K), R8.2
unnamed: D9.1 (K), R9.2
unnamed: D10.1 (K), R10.2
unnamed: J1.1, R6.1, R7.1, R8.1, R9.1, R10.1
unnamed: J1.3, R1.2, R2.2, R3.2, R4.2, R5.2

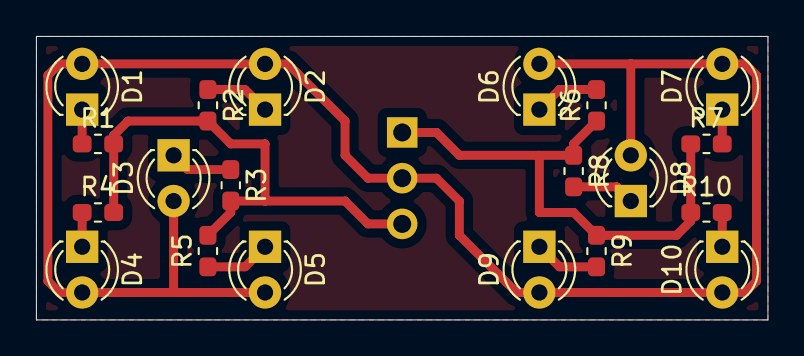
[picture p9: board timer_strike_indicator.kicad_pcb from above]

Board: 2 copper layers, 40.6 x 15.7 mm, 21 parts (1 on the bottom side), 13 nets.

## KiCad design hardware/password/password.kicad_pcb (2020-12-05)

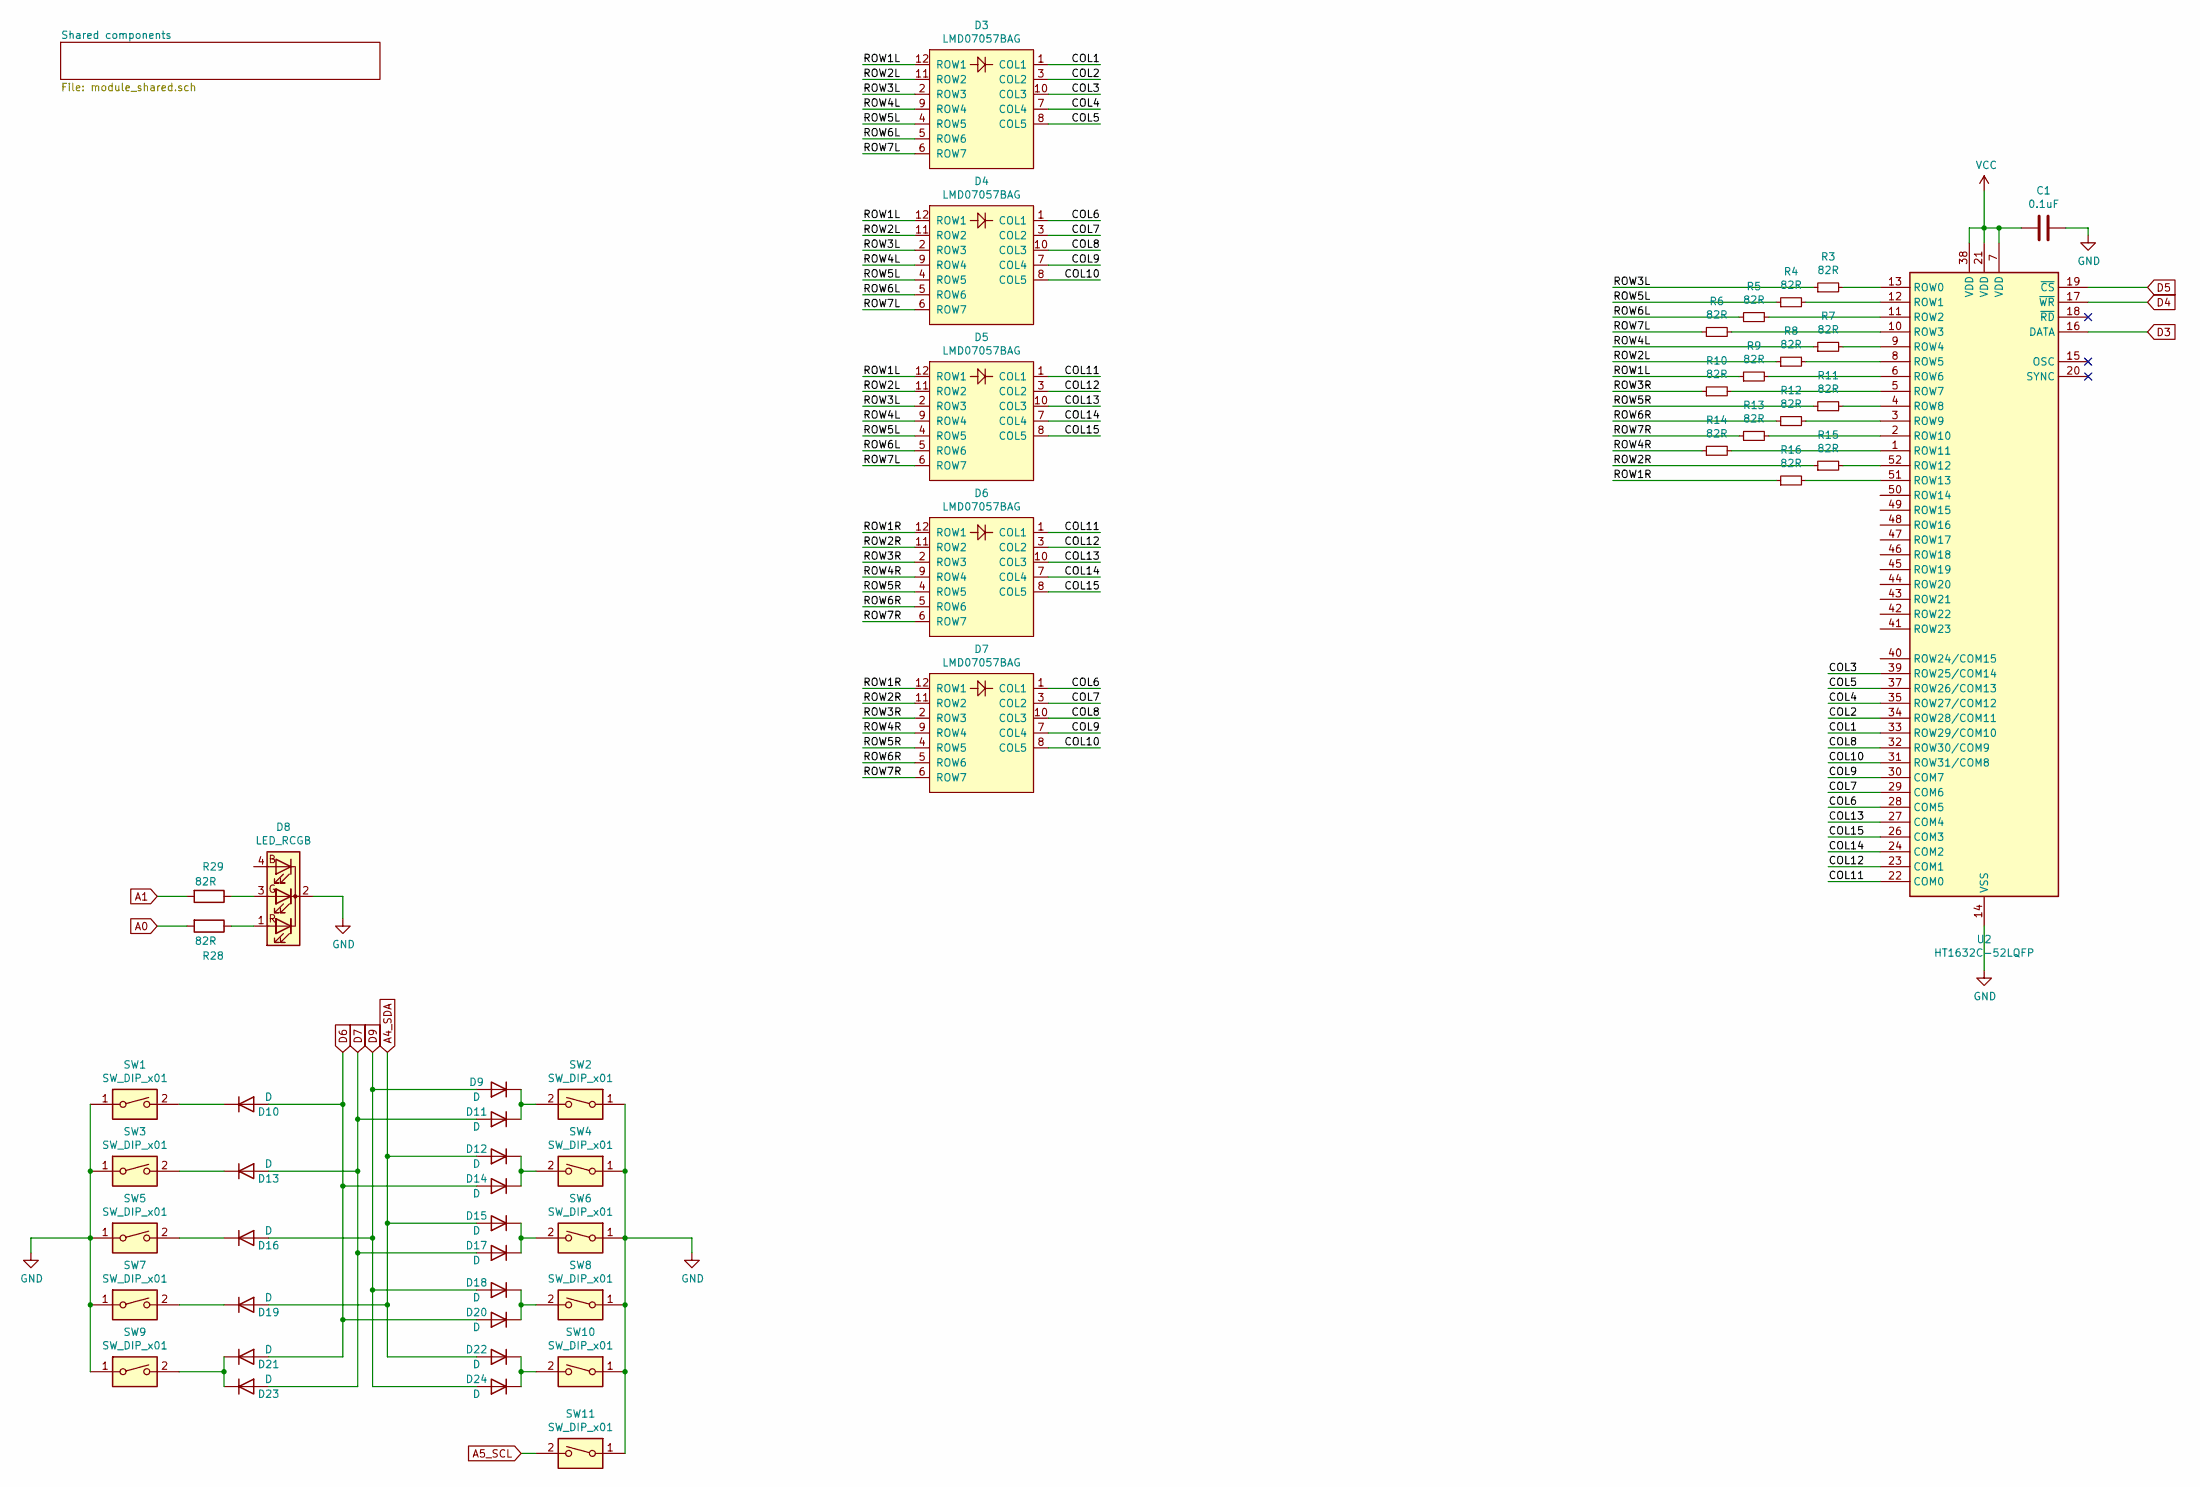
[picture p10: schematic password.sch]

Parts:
C1: 0.1uF; C_0603_1608Metric_Pad1.05x0.95mm_HandSolder
D3, D4, D5, D6, D7: LMD07057BAG
D8: LED_RCGB; LED_D5.0mm-4_RGB_Wide_Pins
D9, D10, D11, D12, D13, D14, D15, D16, D17, D18, D19, D20, D21, D22, D23, D24: D; D_0805_2012Metric_Pad1.15x1.40mm_HandSolder
R3, R4, R5, R6, R7, R8, R9, R10, R11, R12, R13, R14, R15, R16, R28, R29: 82R; R_0603_1608Metric_Pad0.98x0.95mm_HandSolder
SW1, SW2, SW3, SW4, SW5, SW6, SW7, SW8, SW9, SW10, SW11: SW_DIP_x01; SW_Push_1P1T_NO_6x6mm_H9.5mm
U2: HT1632C-52LQFP; LQFP-52_14x14mm_P1mm

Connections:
/COL1: D3.1 (COL1), U2.33 (ROW29/COM10)
/COL2: D3.3 (COL2), U2.34 (ROW28/COM11)
/COL3: D3.10 (COL3), U2.39 (ROW25/COM14)
/COL4: D3.7 (COL4), U2.35 (ROW27/COM12)
/COL5: D3.8 (COL5), U2.37 (ROW26/COM13)
/COL6: D4.1 (COL1), D7.1 (COL1), U2.28 (COM5)
/COL7: D4.3 (COL2), D7.3 (COL2), U2.29 (COM6)
/COL8: D4.10 (COL3), D7.10 (COL3), U2.32 (ROW30/COM9)
/COL9: D4.7 (COL4), D7.7 (COL4), U2.30 (COM7)
/COL10: D4.8 (COL5), D7.8 (COL5), U2.31 (ROW31/COM8)
/COL11: D5.1 (COL1), D6.1 (COL1), U2.22 (COM0)
/COL12: D5.3 (COL2), D6.3 (COL2), U2.23 (COM1)
/COL13: D5.10 (COL3), D6.10 (COL3), U2.27 (COM4)
/COL14: D5.7 (COL4), D6.7 (COL4), U2.24 (COM2)
/COL15: D5.8 (COL5), D6.8 (COL5), U2.26 (COM3)
/ROW1L: D3.12 (ROW1), D4.12 (ROW1), D5.12 (ROW1), R9.1
/ROW1R: D6.12 (ROW1), D7.12 (ROW1), R16.1
/ROW2L: D3.11 (ROW2), D4.11 (ROW2), D5.11 (ROW2), R8.1
/ROW2R: D6.11 (ROW2), D7.11 (ROW2), R15.1
/ROW3L: D3.2 (ROW3), D4.2 (ROW3), D5.2 (ROW3), R3.1
/ROW3R: D6.2 (ROW3), D7.2 (ROW3), R10.1
/ROW4L: D3.9 (ROW4), D4.9 (ROW4), D5.9 (ROW4), R7.1
/ROW4R: D6.9 (ROW4), D7.9 (ROW4), R14.1
/ROW5L: D3.4 (ROW5), D4.4 (ROW5), D5.4 (ROW5), R4.1
/ROW5R: D6.4 (ROW5), D7.4 (ROW5), R11.1
/ROW6L: D3.5 (ROW6), D4.5 (ROW6), D5.5 (ROW6), R5.1
/ROW6R: D6.5 (ROW6), D7.5 (ROW6), R12.1
/ROW7L: D3.6 (ROW7), D4.6 (ROW7), D5.6 (ROW7), R6.1
/ROW7R: D6.6 (ROW7), D7.6 (ROW7), R13.1
A0: R28.2; also elsewhere on the board
A1: R29.2; also elsewhere on the board
A4_SDA: D12.2 (A), D15.2 (A), D19.2 (A), D22.2 (A); also elsewhere on the board
A5_SCL: SW11.2; also elsewhere on the board
D3: U2.16 (DATA); also elsewhere on the board
D4: U2.17 (~WR); also elsewhere on the board
D5: U2.19 (~CS); also elsewhere on the board
D6: D10.2 (A), D14.2 (A), D20.2 (A), D21.2 (A); also elsewhere on the board
D7: D11.2 (A), D13.2 (A), D17.2 (A), D23.2 (A); also elsewhere on the board
D9: D9.2 (A), D16.2 (A), D18.2 (A), D24.2 (A); also elsewhere on the board
GND: C1.1, D8.2 (K), SW1.1, SW2.1, SW3.1, SW4.1, SW5.1, SW6.1, SW7.1, SW8.1, SW9.1, SW10.1, SW11.1, U2.14 (VSS), U2.25 (VSS), U2.36 (VSS); also elsewhere on the board
unnamed: D8.1 (RA), R28.1
unnamed: D8.3 (GA), R29.1
unnamed: D10.1 (K), SW1.2
unnamed: D9.1 (K), D11.1 (K), SW2.2
unnamed: D12.1 (K), D14.1 (K), SW4.2
unnamed: D13.1 (K), SW3.2
unnamed: D15.1 (K), D17.1 (K), SW6.2
unnamed: D16.1 (K), SW5.2
unnamed: D18.1 (K), D20.1 (K), SW8.2
unnamed: D19.1 (K), SW7.2
unnamed: D21.1 (K), D23.1 (K), SW9.2
unnamed: D22.1 (K), D24.1 (K), SW10.2
unnamed: R3.2, U2.13 (ROW0)
unnamed: R4.2, U2.12 (ROW1)
unnamed: R5.2, U2.11 (ROW2)
unnamed: R6.2, U2.10 (ROW3)
unnamed: R7.2, U2.9 (ROW4)
unnamed: R8.2, U2.8 (ROW5)
unnamed: R9.2, U2.6 (ROW6)
unnamed: R10.2, U2.5 (ROW7)
unnamed: R11.2, U2.4 (ROW8)
unnamed: R12.2, U2.3 (ROW9)
unnamed: R13.2, U2.2 (ROW10)
unnamed: R14.2, U2.1 (ROW11)
unnamed: R15.2, U2.52 (ROW12)
unnamed: R16.2, U2.51 (ROW13)
VCC: C1.2, U2.7 (VDD), U2.21 (VDD), U2.38 (VDD); also elsewhere on the board


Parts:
A1: Arduino_Nano_v3.x; Arduino_Nano
D1, D2: LED_Small; LED_D3.0mm
J1: RJ45_Shielded; RJ45_5224
R1, R2: 560R; R_0603_1608Metric_Pad0.98x0.95mm_HandSolder
U1: WAVGAT_CAN

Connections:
+12V: J1.2
A0: A1.19 (A0); also elsewhere on the board
A1: A1.20 (A1); also elsewhere on the board
A4_SDA: A1.23 (A4); also elsewhere on the board
A5_SCL: A1.24 (A5); also elsewhere on the board
A6: A1.25 (A6)
A7: A1.26 (A7)
D3: A1.6 (D3); also elsewhere on the board
D4: A1.7 (D4); also elsewhere on the board
D5: A1.8 (D5); also elsewhere on the board
D6: A1.9 (D6); also elsewhere on the board
D7: A1.10 (D7); also elsewhere on the board
D9: A1.12 (D9); also elsewhere on the board
D10: A1.13 (D10)
GND: A1.4 (GND), A1.29 (GND), D1.1 (K), D2.1 (K), J1.1, J1.7, J1.SH, U1.J4_6 (GND); also elsewhere on the board
MISO: A1.15 (D12), U1.J4_4 (MISO)
MODULE_ENABLE: A1.22 (A3), J1.5, R2.2
MODULE_READY: A1.21 (A2), J1.4
MOSI: A1.14 (D11), U1.J4_3 (MOSI)
unnamed: A1.5 (D2), U1.J4_1 (INT)
unnamed: A1.11 (D8), U1.J4_5 (CS/SS)
unnamed: D1.2 (A), R1.2
unnamed: D2.2 (A), R2.1
unnamed: J1.3, U1.J3_1 (CAN_L)
unnamed: J1.6, U1.J3_2 (CAN_H)
SCK: A1.16 (D13), U1.J4_2 (SCK)
VCC: A1.27 (+5V), J1.8, R1.1, U1.J4_7 (VCC); also elsewhere on the board

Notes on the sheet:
PWM: D3, D5, D6, D9, D10, D11

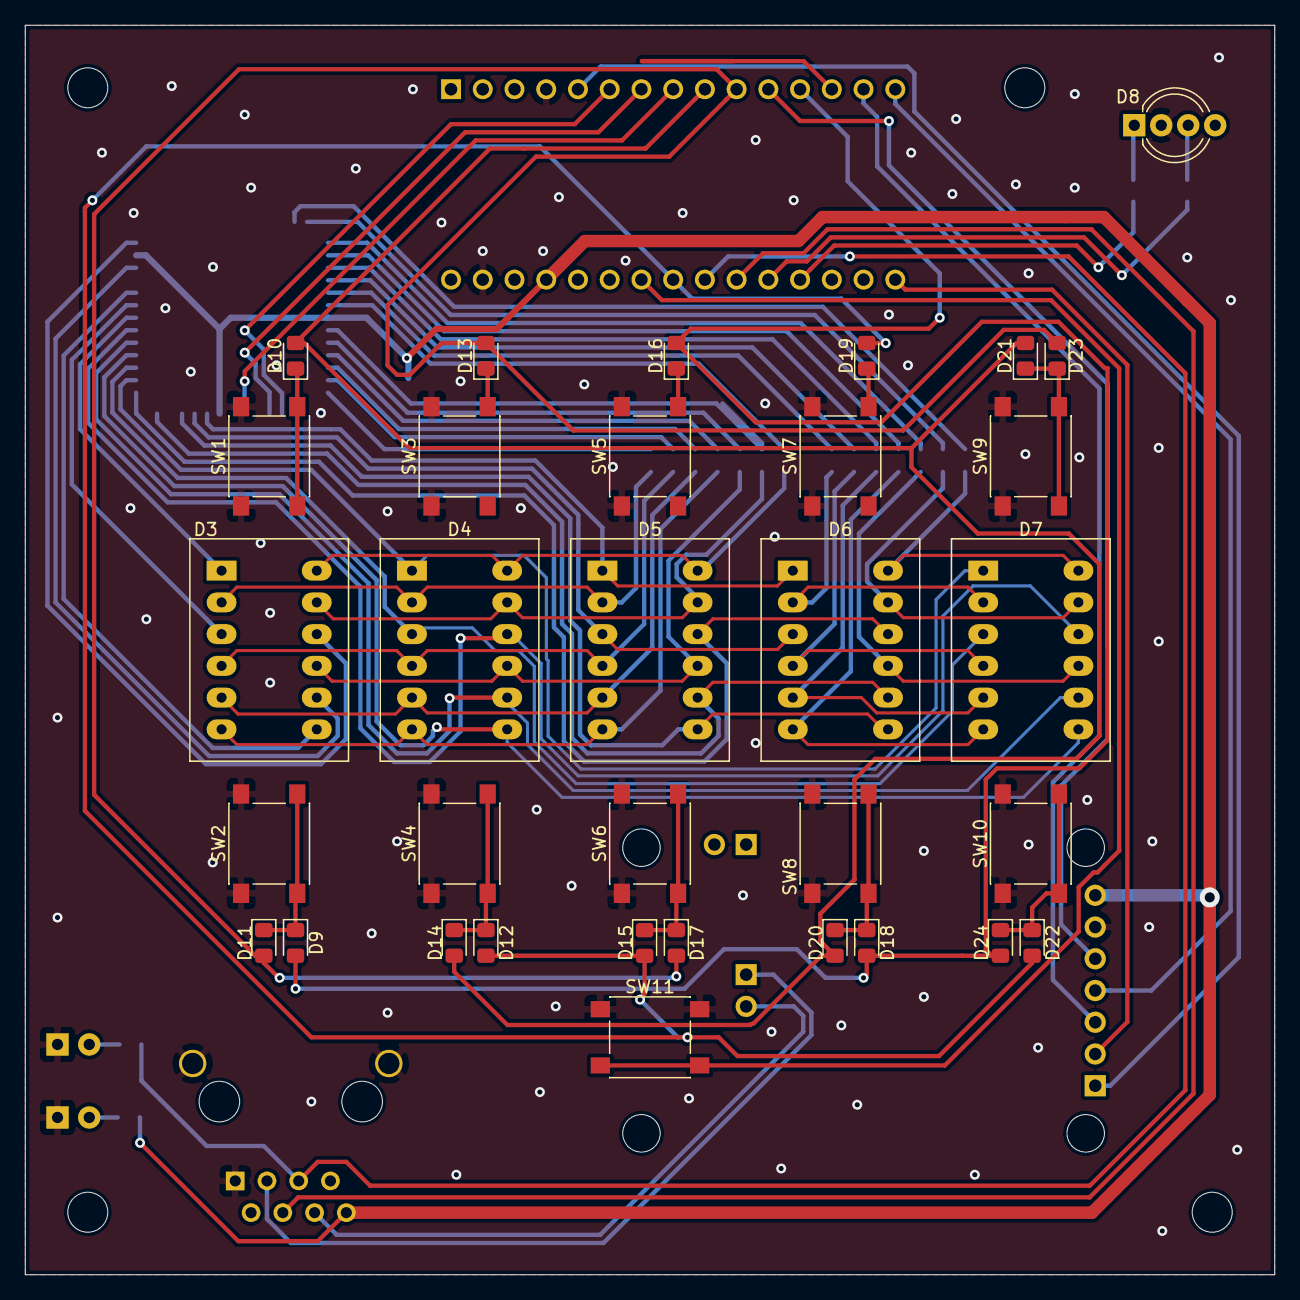
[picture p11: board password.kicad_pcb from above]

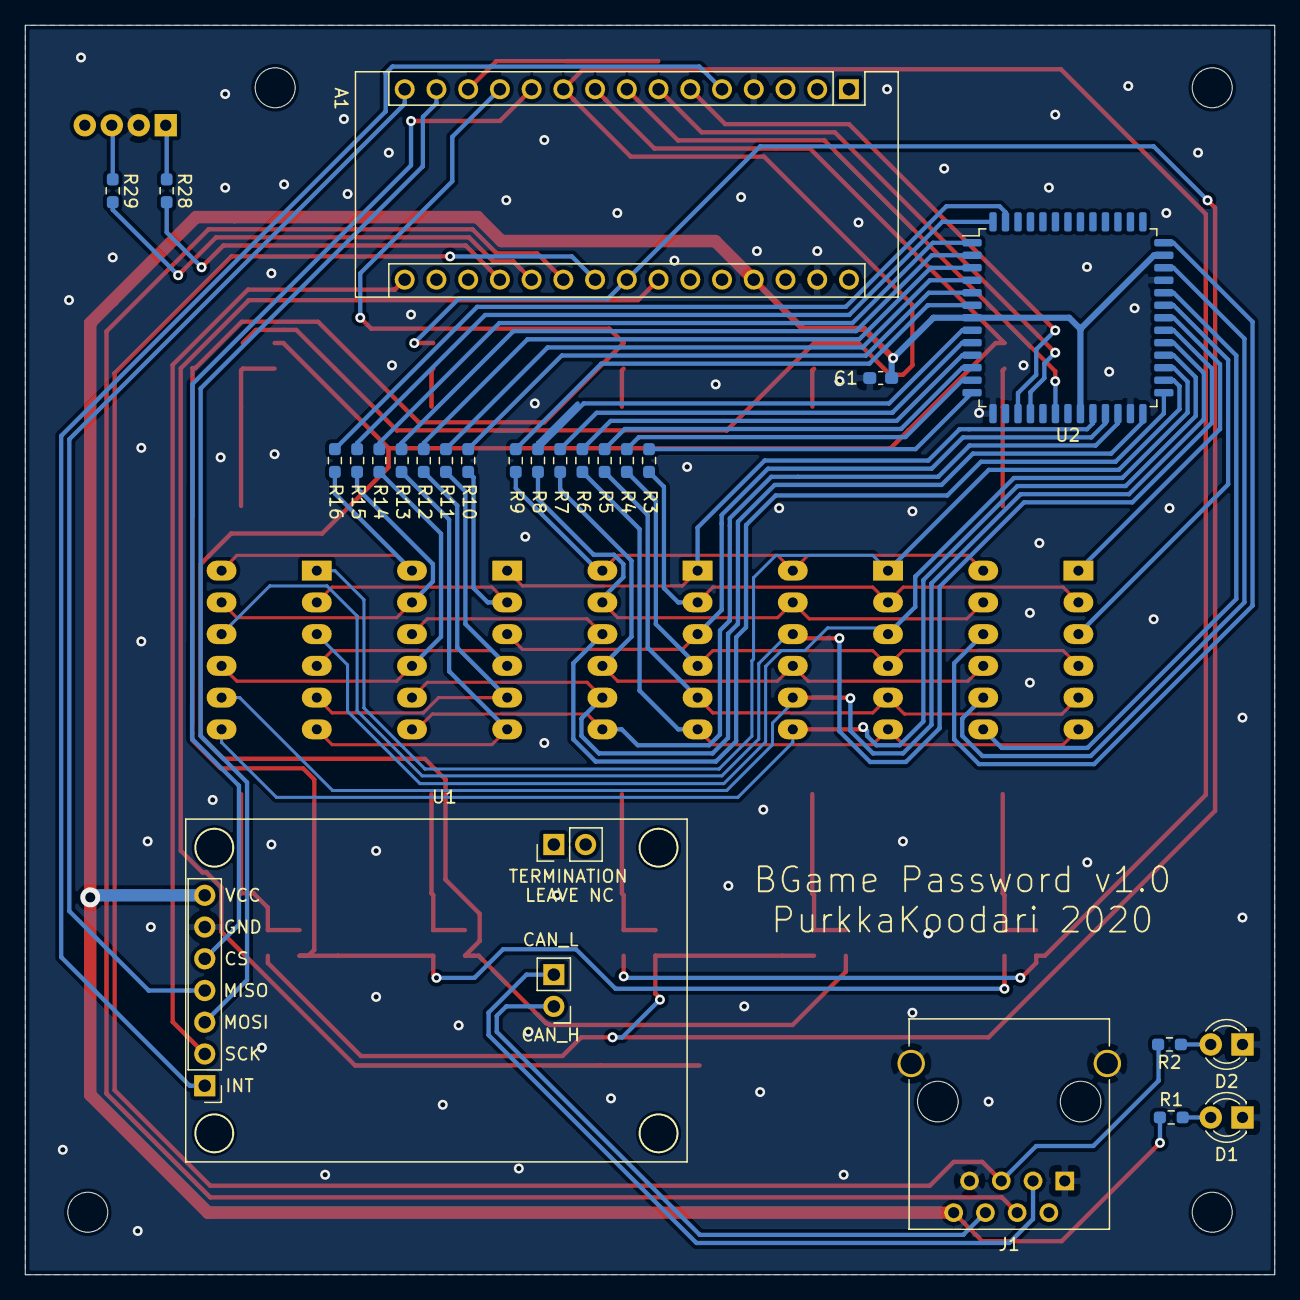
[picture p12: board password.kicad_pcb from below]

Board: 2 copper layers, 100.0 x 100.0 mm, 58 parts (25 on the bottom side), 78 nets.

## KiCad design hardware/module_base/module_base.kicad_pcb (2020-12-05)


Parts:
C1, C2: 0.1uF; C_0603_1608Metric_Pad1.08x0.95mm_HandSolder
J2: Conn_01x24_Female; PinSocket_1x24_P2.54mm_Vertical
J3: Conn_01x36_Female; PinSocket_1x36_P2.54mm_Vertical
J4, J5: Conn_01x15_Female; PinSocket_1x15_P2.54mm_Vertical
Q1, Q2, Q3, Q4, Q5, Q6: Q_NMOS_GSD; SOT-23_Handsoldering
R3, R4: 4K7; R_0603_1608Metric_Pad0.98x0.95mm_HandSolder
R5, R6, R7, R8, R9, R10: 0R; R_0603_1608Metric_Pad0.98x0.95mm_HandSolder
U2: HT1632C-52LQFP; QFP-52_14x14_Pitch1mm_HandSoldering
U3: HT16K33; SOIC-28W_7.5x17.9mm_P1.27mm

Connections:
+3V3: J4.2; also elsewhere on the board
+12V: J3.19; also elsewhere on the board
A0: J4.4, Q6.1 (G); also elsewhere on the board
A1: J4.5; also elsewhere on the board
A2_MODULE_READY: J4.6; also elsewhere on the board
A3_MODULE_ENABLE: J4.7; also elsewhere on the board
A4_SDA: J3.21, J4.8, R3.1, U3.27 (SDA); also elsewhere on the board
A5_SCL: J3.20, J4.9, R4.1, U3.26 (SCL); also elsewhere on the board
A6: J4.10; also elsewhere on the board
A7: J4.11; also elsewhere on the board
AREF: J4.3; also elsewhere on the board
COM0: J3.16, U2.22 (COM0), U3.2 (COM0/AD0)
COM1: J3.15, U2.23 (COM1), U3.3 (COM1/KS0)
COM2: J3.14, U2.24 (COM2), U3.4 (COM2/KS1)
COM3: J3.13, U2.26 (COM3), U3.5 (COM3/KS2)
COM4: J3.12, U2.27 (COM4), U3.6 (COM4)
COM5: J3.11, U2.28 (COM5), U3.7 (COM5)
COM6: J3.10, U2.29 (COM6), U3.8 (COM6)
COM7: J3.9, U2.30 (COM7), U3.9 (COM7)
D0_RX: J5.14; also elsewhere on the board
D1_TX: J5.15; also elsewhere on the board
D2_CAN_INT: J5.11; also elsewhere on the board
D3: J5.10, Q1.1 (G), U2.16 (DATA); also elsewhere on the board
D4: J5.9, U2.17 (~WR); also elsewhere on the board
D5: J5.8, Q2.1 (G), U2.19 (~CS); also elsewhere on the board
D6: J5.7, Q3.1 (G); also elsewhere on the board
D7: J5.6; also elsewhere on the board
D8_CAN_CS: J5.5; also elsewhere on the board
D9: J5.4, Q4.1 (G); also elsewhere on the board
D10: J5.3, Q5.1 (G); also elsewhere on the board
D11_MOSI: J3.24, J5.2; also elsewhere on the board
D12_MISO: J3.23, J5.1; also elsewhere on the board
D13_SCK: J3.22, J4.1; also elsewhere on the board
GND: C1.2, C2.2, J3.31, J3.32, J3.33, J3.34, J3.35, J3.36, J4.14, J5.12, Q1.2 (S), Q2.2 (S), Q3.2 (S), Q4.2 (S), Q5.2 (S), Q6.2 (S), U2.14 (VSS), U2.25 (VSS), U2.36 (VSS), U3.1 (VSS); also elsewhere on the board
unnamed: J2.17, U2.48 (ROW16)
unnamed: J2.18, U2.47 (ROW17)
unnamed: J2.19, U2.46 (ROW18)
unnamed: J2.20, U2.45 (ROW19)
unnamed: J2.21, U2.44 (ROW20)
unnamed: J2.22, U2.43 (ROW21)
unnamed: J2.23, U2.42 (ROW22)
unnamed: J2.24, U2.41 (ROW23)
unnamed: J3.1, U2.40 (ROW24/COM15)
unnamed: J3.2, U2.39 (ROW25/COM14)
unnamed: J3.3, U2.37 (ROW26/COM13)
unnamed: J3.4, U2.35 (ROW27/COM12)
unnamed: J3.5, U2.34 (ROW28/COM11)
unnamed: J3.6, U2.33 (ROW29/COM10)
unnamed: J3.7, U2.32 (ROW30/COM9)
unnamed: J3.8, U2.31 (ROW31/COM8)
unnamed: J3.25, R5.1
unnamed: J3.26, R6.1
unnamed: J3.27, R7.1
unnamed: J3.28, R8.1
unnamed: J3.29, R9.1
unnamed: J3.30, R10.1
unnamed: Q1.3 (D), R5.2
unnamed: Q2.3 (D), R6.2
unnamed: Q3.3 (D), R7.2
unnamed: Q4.3 (D), R8.2
unnamed: Q5.3 (D), R9.2
unnamed: Q6.3 (D), R10.2
ROW0: J2.1, U2.13 (ROW0), U3.25 (ROW0/A2)
ROW1: J2.2, U2.12 (ROW1), U3.24 (ROW1/A1)
ROW2: J2.3, U2.11 (ROW2), U3.23 (ROW2/A0)
ROW3: J2.4, U2.10 (ROW3), U3.22 (ROW3/K1)
ROW4: J2.5, U2.9 (ROW4), U3.21 (ROW4/K2)
ROW5: J2.6, U2.8 (ROW5), U3.20 (ROW5/K3)
ROW6: J2.7, U2.6 (ROW6), U3.19 (ROW6/K4)
ROW7: J2.8, U2.5 (ROW7), U3.18 (ROW7/K5)
ROW8: J2.9, U2.4 (ROW8), U3.17 (ROW8/K6)
ROW9: J2.10, U2.3 (ROW9), U3.16 (ROW9/K7)
ROW10: J2.11, U2.2 (ROW10), U3.15 (ROW10/K8)
ROW11: J2.12, U2.1 (ROW11), U3.14 (ROW11/K9)
ROW12: J2.13, U2.52 (ROW12), U3.13 (ROW12/K10)
ROW13: J2.14, U2.51 (ROW13), U3.12 (ROW13/K11)
ROW14: J2.15, U2.50 (ROW14), U3.11 (ROW14/K12)
ROW15: J2.16, U2.49 (ROW15), U3.10 (ROW15/K13/INT)
RST: J4.13, J5.13; also elsewhere on the board
VCC: C1.1, C2.1, J3.17, J3.18, J4.12, R3.2, R4.2, U2.7 (VDD), U2.21 (VDD), U2.38 (VDD), U3.28 (VDD); also elsewhere on the board
VIN: J4.15; also elsewhere on the board


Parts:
A1: Arduino_Nano_v3.x; Arduino_Nano
D1, D2: LED_Small; LED_D3.0mm
J1: RJ45_Shielded; RJ45_5224
R1, R2: 560R; R_0603_1608Metric_Pad0.98x0.95mm_HandSolder
U1: WAVGAT_CAN

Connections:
+3V3: A1.17 (3V3); also elsewhere on the board
+12V: J1.2; also elsewhere on the board
A0: A1.19 (A0); also elsewhere on the board
A1: A1.20 (A1); also elsewhere on the board
A2_MODULE_READY: A1.21 (A2), J1.4; also elsewhere on the board
A3_MODULE_ENABLE: A1.22 (A3), J1.5, R2.2; also elsewhere on the board
A4_SDA: A1.23 (A4); also elsewhere on the board
A5_SCL: A1.24 (A5); also elsewhere on the board
A6: A1.25 (A6); also elsewhere on the board
A7: A1.26 (A7); also elsewhere on the board
AREF: A1.18 (AREF); also elsewhere on the board
D0_RX: A1.2 (D0/RX); also elsewhere on the board
D1_TX: A1.1 (D1/TX); also elsewhere on the board
D2_CAN_INT: A1.5 (D2), U1.J4_1 (INT); also elsewhere on the board
D3: A1.6 (D3); also elsewhere on the board
D4: A1.7 (D4); also elsewhere on the board
D5: A1.8 (D5); also elsewhere on the board
D6: A1.9 (D6); also elsewhere on the board
D7: A1.10 (D7); also elsewhere on the board
D8_CAN_CS: A1.11 (D8), U1.J4_5 (CS/SS); also elsewhere on the board
D9: A1.12 (D9); also elsewhere on the board
D10: A1.13 (D10); also elsewhere on the board
D11_MOSI: A1.14 (D11), U1.J4_3 (MOSI); also elsewhere on the board
D12_MISO: A1.15 (D12), U1.J4_4 (MISO); also elsewhere on the board
D13_SCK: A1.16 (D13), U1.J4_2 (SCK); also elsewhere on the board
GND: A1.4 (GND), A1.29 (GND), D1.1 (K), D2.1 (K), J1.1, J1.7, J1.SH, U1.J4_6 (GND); also elsewhere on the board
unnamed: D1.2 (A), R1.2
unnamed: D2.2 (A), R2.1
unnamed: J1.3, U1.J3_1 (CAN_L)
unnamed: J1.6, U1.J3_2 (CAN_H)
RST: A1.3 (~RESET), A1.28 (~RESET); also elsewhere on the board
VCC: A1.27 (+5V), J1.8, R1.1, U1.J4_7 (VCC); also elsewhere on the board
VIN: A1.30 (VIN); also elsewhere on the board

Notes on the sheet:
PWM: D3, D5, D6, D9, D10, D11



Board: 2 copper layers, 100.0 x 100.0 mm, 29 parts (20 on the bottom side), 85 nets.

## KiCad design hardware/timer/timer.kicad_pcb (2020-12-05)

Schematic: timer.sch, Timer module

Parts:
C1: 0.1uF; C_0603_1608Metric_Pad1.05x0.95mm_HandSolder
D3: 8402BS
J2: Conn_01x03_Female; PinSocket_1x03_P2.54mm_Vertical
R3, R4: 4K7; R_0603_1608Metric_Pad1.05x0.95mm_HandSolder
R5, R6, R7, R8, R9: 100; R_0603_1608Metric_Pad1.05x0.95mm_HandSolder
U2: HT16K33; SOIC-28W_7.5x17.9mm_P1.27mm

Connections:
A0: J2.3; also elsewhere on the board
A1: J2.1; also elsewhere on the board
A4_SDA: R3.1, U2.27; also elsewhere on the board
A5_SCL: R4.1, U2.26; also elsewhere on the board
GND: C1.1, U2.1; also elsewhere on the board
unnamed: D3.1, U2.9
unnamed: D3.2, U2.8
unnamed: D3.3, D3.8, U2.7
unnamed: D3.4, U2.6
unnamed: D3.5, U2.5
unnamed: D3.6, R8.1
unnamed: D3.7, R9.1
unnamed: D3.9, U2.4
unnamed: D3.10, R7.1
unnamed: D3.11, R6.1
unnamed: D3.12, U2.3
unnamed: D3.13, U2.2
unnamed: D3.14, R5.1
unnamed: R5.2, U2.25
unnamed: R6.2, U2.24
unnamed: R7.2, U2.23
unnamed: R8.2, U2.22
unnamed: R9.2, U2.21
VCC: C1.2, J2.2, R3.2, R4.2, U2.28; also elsewhere on the board

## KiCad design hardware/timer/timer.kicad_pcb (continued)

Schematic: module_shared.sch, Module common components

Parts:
A1: Arduino_Nano_v3.x; Arduino_Nano
D1, D2: LED_Small; LED_D3.0mm
J1: RJ45_Shielded; RJ45_5224
R1, R2: 560R; R_0603_1608Metric_Pad1.05x0.95mm_HandSolder
U1: WAVGAT_CAN

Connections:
+12V: J1.2
A0: A1.19; also elsewhere on the board
A1: A1.20; also elsewhere on the board
A4_SDA: A1.23; also elsewhere on the board
A5_SCL: A1.24; also elsewhere on the board
A6: A1.25
A7: A1.26
D3: A1.6
D4: A1.7
D5: A1.8
D6: A1.9
D7: A1.10
D9: A1.12
D10: A1.13
GND: A1.4, A1.29, D1.1, D2.1, J1.1, J1.7, J1.SH, U1.J4_6; also elsewhere on the board
MISO: A1.15, U1.J4_4
MODULE_ENABLE: A1.22, J1.5, R2.2
MODULE_READY: A1.21, J1.4
MOSI: A1.14, U1.J4_3
unnamed: A1.5, U1.J4_1
unnamed: A1.11, U1.J4_5
unnamed: D1.2, R2.1
unnamed: D2.2, R1.2
unnamed: J1.3, U1.J3_1
unnamed: J1.6, U1.J3_2
SCK: A1.16, U1.J4_2
VCC: A1.27, J1.8, R1.1, U1.J4_7; also elsewhere on the board

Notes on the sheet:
PWM: D3, D5, D6, D9, D10, D11



Board: 2 copper layers, 100.0 x 100.0 mm, 18 parts (16 on the bottom side), 35 nets.

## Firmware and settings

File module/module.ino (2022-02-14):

#include <mcp2515.h>
#include <can.h>

#include "module.h"

#include "timer.h"
#include "wires.h"
#include "password.h"
#include "simon.h"
#include "ventinggas.h"
#include "button.h"
#include "keypad.h"

//////////////////////////// SANITY CHECKS ////////////////////////////

#ifndef MODULE_TYPE
#error "No module type set."
#endif
#if MODULE_TYPE <= 0
#error "Module id can't be zero or negative."
#endif
#if MODULE_TYPE > MODULEID_TYPE_MAX
#error "Too large module id."
#endif

#if MODULE_SERIAL < 0
#error "Module serial can't be negative."
#endif
#if MODULE_SERIAL > MODULEID_SERIAL_MAX
#error "Too large module serial."
#endif

#ifndef MODULE_NAME
#error "No module name set. New module and header not #included in module.ino?"
#endif

#if !defined(NO_STATUS_LED) && (!defined(STRIKE_LED_PIN) || !defined(SOLVE_LED_PIN))
#error "Either NO_STATUS_LED or STRIKE_LED_PIN and SOLVE_LED_PIN must be defined"
#endif

//////////////////////////// GLOBAL DATA ////////////////////////////

enum module_mode mode = RESET;
bool solved = false;
unsigned long strike_until = 0;
bool timer_started = false;
bool game_ended = false;
bool exploded = false;

//////////////////////////// CAN MESSAGING ////////////////////////////

MCP2515 canBus(MCP_CS_PIN);
struct can_frame canFrame;

volatile bool incoming = false;

void messageReceived() {
  incoming = true;
}

void sendMessage(uint16_t message_id, uint8_t dlc) {
  canFrame.can_id = CAN_EFF_FLAG | CAN_TX_ID | (message_id << MESSAGE_ID_OFFSET);
  canFrame.can_dlc = dlc;
#ifdef DEBUG_CAN_MESSAGES
#ifdef DEBUG
  DEBUG_PRINT("TX id ");
  DEBUG_PRINT2(canFrame.can_id, 16);
  DEBUG_PRINT(" dlc ");
  DEBUG_PRINT2(canFrame.can_dlc, 16);
  DEBUG_PRINT(" data");
  for (int i = 0; i < canFrame.can_dlc; i++) {
    DEBUG_PRINT(" ");
    DEBUG_PRINT2(canFrame.data[i], 16);
  }
  DEBUG_PRINTLN("");
#endif
#endif
  if (canBus.sendMessage(&canFrame) != MCP2515::ERROR_OK) {
    DEBUG_PRINTLN("TX failed");
  } else {
    DEBUG_PRINTLN("TX succeeded");
  }
}

void sendError(uint16_t message_id, uint8_t code) {
  ((struct error_data *) &canFrame.data)->code = code;
  sendMessage(message_id, 1);
}

//////////////////////////// DEFAULT EMPTY EVENT HANDLERS ////////////////////////////

__attribute__((weak)) void moduleReset() {}
__attribute__((weak)) void moduleStartGame() {}
__attribute__((weak)) void moduleStartTimer() {}
__attribute__((weak)) void moduleExplode() {}
__attribute__((weak)) void moduleDefuse() {}
__attribute__((weak)) void moduleSolve() {}
__attribute__((weak)) void moduleStrike() {}
__attribute__((weak)) void moduleNeedyActivate() {}
__attribute__((weak)) void moduleNeedyDeactivate() {}

//////////////////////////// MAIN FUNCTIONS ////////////////////////////

void initHardware() {
  pinMode(MODULE_READY_PIN, OUTPUT);
  pinMode(MODULE_ENABLE_PIN, INPUT);
#ifndef NO_STATUS_LED
  pinMode(STRIKE_LED_PIN, OUTPUT);
  digitalWrite(STRIKE_LED_PIN, LOW);
  pinMode(SOLVE_LED_PIN, OUTPUT);
  digitalWrite(SOLVE_LED_PIN, LOW);
#endif
  moduleInitHardware();
}

void resetModule() {
  DEBUG_PRINTLN("Resetting module");
  mode = RESET;
  digitalWrite(MODULE_READY_PIN, LOW);
  timer_started = false;
  game_ended = false;
  exploded = false;
  solved = false;
  strike_until = 0;
  moduleReset();
}

void handleMessage() {
#ifdef DEBUG_CAN_MESSAGES
#ifdef DEBUG
  DEBUG_PRINT("RX id ");
  DEBUG_PRINT2(canFrame.can_id, 16);
  DEBUG_PRINT(" dlc ");
  DEBUG_PRINT2(canFrame.can_dlc, 16);
  DEBUG_PRINT(" data");
  for (int i = 0; i < canFrame.can_dlc; i++) {
    DEBUG_PRINT(" ");
    DEBUG_PRINT2(canFrame.data[i], 16);
  }
  DEBUG_PRINTLN("");
#endif
#endif

  uint16_t messageId = (uint16_t) ((canFrame.can_id & MESSAGE_ID_MASK) >> MESSAGE_ID_OFFSET);

  if (messageId == MESSAGE_RESET) {
    resetModule();
    return;
  }

  if (mode == RESET) return;
  
  switch (messageId) {
  case MESSAGE_PING:
    DEBUG_PRINT("Responding to ping ");
    DEBUG_PRINTLN(((struct ping_data *) &canFrame.data)->number);
    sendMessage(MESSAGE_PING, 1);
    break;
  case MESSAGE_LAUNCH_GAME:
    if (mode != CONFIGURATION) {
      DEBUG_PRINTLN("MESSAGE_LAUNCH_GAME received in bad mode");
      sendError(MESSAGE_RECOVERED_ERROR, ERROR_INVALID_MESSAGE);
      return;
    }
    DEBUG_PRINTLN("Game starting!");
    mode = GAME;
    moduleStartGame();
    break;
  case MESSAGE_START_TIMER:
    DEBUG_PRINTLN("Timer starting!");
    timer_started = true;
    moduleStartTimer();
    break;
  case MESSAGE_EXPLODE:
    DEBUG_PRINTLN("Bomb exploded!");
    game_ended = true;
    exploded = true;
    moduleExplode();
    break;
  case MESSAGE_DEFUSE:
    DEBUG_PRINTLN("Bomb defused!");
    game_ended = true;
    moduleDefuse();
    break;
  case MESSAGE_STRIKE:
    strike_until = millis() + 1000;
    moduleStrike();
    break;
  case MESSAGE_SOLVE:
    strike_until = 0;
    solved = true;
    moduleSolve();
    break;
  case MESSAGE_NEEDY_ACTIVATE:
    moduleNeedyActivate();
    break;
  case MESSAGE_NEEDY_DEACTIVATE:
    moduleNeedyDeactivate();
    break;
  case MESSAGE_MODULE_SPECIFIC_0:
  case MESSAGE_MODULE_SPECIFIC_1:
  case MESSAGE_MODULE_SPECIFIC_2:
  case MESSAGE_MODULE_SPECIFIC_3:
  case MESSAGE_MODULE_SPECIFIC_4:
  case MESSAGE_MODULE_SPECIFIC_5:
  case MESSAGE_MODULE_SPECIFIC_6:
  case MESSAGE_MODULE_SPECIFIC_7:
  case MESSAGE_MODULE_SPECIFIC_8:
  case MESSAGE_MODULE_SPECIFIC_9:
  case MESSAGE_MODULE_SPECIFIC_A:
  case MESSAGE_MODULE_SPECIFIC_B:
  case MESSAGE_MODULE_SPECIFIC_C:
  case MESSAGE_MODULE_SPECIFIC_D:
  case MESSAGE_MODULE_SPECIFIC_E:
  case MESSAGE_MODULE_SPECIFIC_F:
    if (moduleHandleMessage(messageId))
      break;
    [[fallthrough]];
  default:
    DEBUG_PRINTLN("Unknown message received");
    sendError(MESSAGE_RECOVERED_ERROR, ERROR_INVALID_MESSAGE);
    break;
  }
}

void setup() {
  Serial.begin(9600);
  Serial.println("BombGame module starting");
  Serial.println("Module: " MODULE_NAME " (id " QUOTE2(MODULE_TYPE) ")");
  Serial.println("Version: HW/" QUOTE2(VERSION_HW_MAJOR) "." QUOTE2(VERSION_HW_MINOR) " SW/" QUOTE2(VERSION_SW_MAJOR) "." QUOTE2(VERSION_SW_MINOR));
  DEBUG_PRINTLN("CAN init");
  while (true) {
    if (canBus.reset() != MCP2515::ERROR_OK) goto can_init_fail;
    if (canBus.setBitrate(CAN_100KBPS, MCP_8MHZ) != MCP2515::ERROR_OK) goto can_init_fail;
    if (canBus.setFilterMask(MCP2515::MASK0, true, CAN_RX_MASK) != MCP2515::ERROR_OK) goto can_init_fail;
    if (canBus.setFilter(MCP2515::RXF0, true, CAN_UNICAST_FILTER) != MCP2515::ERROR_OK) goto can_init_fail;
    if (canBus.setFilter(MCP2515::RXF1, true, CAN_BROADCAST_FILTER) != MCP2515::ERROR_OK) goto can_init_fail;
    if (canBus.setNormalMode() != MCP2515::ERROR_OK) goto can_init_fail;
    break;
    can_init_fail:
    Serial.println("CAN init failed, retrying");
    delay(100);
  }
  DEBUG_PRINTLN("CAN init success");
  initHardware();
  resetModule();
  attachInterrupt(digitalPinToInterrupt(MCP_INTERRUPT_PIN), messageReceived, FALLING);
  Serial.println("Module init success");
}

void loop() {
  if (mode == RESET && !digitalRead(MODULE_ENABLE_PIN)) {
    digitalWrite(MODULE_READY_PIN, HIGH);
    DEBUG_PRINTLN("Announcing module");
    *(struct announce_data *) &canFrame.data = {
      VERSION_HW_MAJOR, VERSION_HW_MINOR,
      VERSION_SW_MAJOR, VERSION_SW_MINOR,
      ANNOUNCE_FLAG_INIT_COMPLETE
    };
    sendMessage(MESSAGE_ANNOUNCE, 5);
    mode = CONFIGURATION;
  }
  
#ifndef NO_STATUS_LED
  if (mode == GAME && !exploded) {
    if (solved) {
      digitalWrite(STRIKE_LED_PIN, LOW);
      digitalWrite(SOLVE_LED_PIN, HIGH);
    } else if (millis() < strike_until) {
      digitalWrite(STRIKE_LED_PIN, HIGH);
      digitalWrite(SOLVE_LED_PIN, LOW);
    } else {
      digitalWrite(STRIKE_LED_PIN, LOW);
      digitalWrite(SOLVE_LED_PIN, LOW);
    }
  } else {
    digitalWrite(STRIKE_LED_PIN, LOW);
    digitalWrite(SOLVE_LED_PIN, LOW);
  }
#endif

  moduleLoop();
  
  if (incoming) {
    uint8_t intByte = canBus.getInterrupts();
    if (intByte & MCP2515::CANINTF_RX0IF) {
      if (canBus.readMessage(MCP2515::RXB0, &canFrame) == MCP2515::ERROR_OK) {
        handleMessage();
      } else {
        DEBUG_PRINTLN("Read from RXB0 failed");
      }
    }
    if (intByte & MCP2515::CANINTF_RX1IF) {
      if (canBus.readMessage(MCP2515::RXB1, &canFrame) == MCP2515::ERROR_OK) {
        handleMessage();
      } else {
        DEBUG_PRINTLN("Read from RXB1 failed");
      }
    }
    if (intByte & MCP2515::CANINTF_MERRF) {
      DEBUG_PRINTLN("Message error");
      canBus.clearMERR();
    }
    if (intByte & MCP2515::CANINTF_ERRIF) {
      uint8_t errByte = canBus.getErrorFlags();
      canBus.clearRXnOVR();
      DEBUG_PRINTLN("MCP2515 error state:");
      if (errByte & MCP2515::EFLG_RX1OVR) {
        DEBUG_PRINTLN("RXB1 overflow");
      }
      if (errByte & MCP2515::EFLG_RX0OVR) {
        DEBUG_PRINTLN("RXB0 overflow");
      }
      if (errByte & MCP2515::EFLG_TXBO) {
        DEBUG_PRINTLN("Bus-Off mode");
      }
      if (errByte & MCP2515::EFLG_TXEP) {
        DEBUG_PRINTLN("TX Error-Passive");
      }
      if (errByte & MCP2515::EFLG_RXEP) {
        DEBUG_PRINTLN("RX Error-Passive");
      }
    }
  }
}

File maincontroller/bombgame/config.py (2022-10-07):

from bombgame.casings import VanillaCasing

# the physical bomb casing mounted on the RasPi
BOMB_CASING = VanillaCasing()

# the configuration for can.Bus
CAN_CONFIG = {"interface": "socketcan", "channel": "can0"}

# the URL of the room server, or None if none is in use
# example: ROOM_SERVER = "ws://192.168.0.123:8082/"
ROOM_SERVER = None
# the authentication key for the room server
ROOM_SERVER_AUTH_KEY = "password"  # TODO: change for production use
# the port to host the room server on (only relevant when running room server on this machine)
ROOM_SERVER_PORT = 8082
# the timeout for authentication, in seconds (only relevant when running room server on this machine)
ROOM_SERVER_AUTH_TIMEOUT = 2

# whether or not audio playback commands should be sent to the room server
ROOM_AUDIO_ENABLED = True
# whether or not music should be played by the room server
ROOM_MUSIC_ENABLED = True
# whether or not DMX commands should be sent to the room server
ROOM_DMX_ENABLED = True
# whether or not to host the Web UI on the room server
ROOM_WEB_UI_ENABLED = False

# the API URL of the QLC+ light controller, or None if none is in use
# example: DMX_SERVER = "ws://127.0.0.1:9999/qlcplusWS"
DMX_SERVER = None

# how many simultaneous sound effects to support
AUDIO_CHANNELS = 16
# sound and music volume (should be less than 1 to avoid mix clipping)
SOUND_VOLUME = 0.25
MUSIC_VOLUME = 0.25

# how often to manually check GPIO pins for changes
GPIO_POLL_INTERVAL = 1.0
# the address of the I2C bus where the expanders are connected
GPIO_SMBUS_ADDR = 1
# whether or not to enable GPIO interrupts
GPIO_INTERRUPT_ENABLED = True
# the RasPi pin where the interrupts are connected
GPIO_INTERRUPT_PIN = 22  # TODO: check actual pin number

# if CAN_ERROR_MAX_COUNT bus errors are encountered in CAN_ERROR_MAX_INTERVAL seconds, a fatal error is raised
CAN_ERROR_MAX_INTERVAL = 15
CAN_ERROR_MAX_COUNT = 10

# websocket runs at 0.0.0.0 on this port
WEB_WS_PORT = 8081
# the password required from the UI
WEB_PASSWORD = None
# the timeout for sending the password, in seconds
WEB_LOGIN_TIMEOUT = 2

# the time waited between sending the reset message and checking which modules are ready
MODULE_RESET_PERIOD = 0.6
# the time waited for a module to respond to the MODULE_ENABLE line
MODULE_ANNOUNCE_TIMEOUT = 1.0
# the time waited after a module's last message before pinging it
# set to slightly over 1s to avoid unnecessarily pinging the timer
MODULE_PING_INTERVAL = 0.99  # TODO: 1.2
# the time waited after sending a ping before causing a ping timeout error
MODULE_PING_TIMEOUT = 1.0

# the time spent in the pre-game wait
GAME_START_DELAY = 5

# the default maximum time
DEFAULT_STARTING_TIME = 900.0
# the default number of strikes before the bomb explodes
DEFAULT_MAX_STRIKES = 3

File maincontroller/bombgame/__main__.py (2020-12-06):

from asyncio import run
from logging import getLogger
from sys import argv

from bombgame.controller import BombGameController
from bombgame.logging import init_logging
from bombgame.utils import handle_sigint

LOGGER = getLogger("Main")


async def main():
    verbose = "-v" in argv
    init_logging(verbose)
    LOGGER.info("Starting. Exit cleanly with SIGINT/Ctrl-C")
    quit_evt = handle_sigint()
    game = BombGameController()
    await game.start()
    await quit_evt.wait()
    await game.stop()
    LOGGER.info("Exiting")

if __name__ == "__main__":
    run(main())

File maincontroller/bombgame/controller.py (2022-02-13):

from asyncio import Task, create_task
from logging import getLogger
from typing import Optional

import can

from bombgame.audio import BombSoundSystem
from bombgame.bomb.bomb import Bomb
from bombgame.bus.bus import BombBus
from bombgame.config import BOMB_CASING, CAN_CONFIG, ROOM_SERVER
from bombgame.dmx import DMXController, initialize_bomb_dmx
from bombgame.events import BombChanged
from bombgame.gpio import Gpio, AbstractGpio
from bombgame.modules import load_modules
from bombgame.roomserver.client import RoomServerClient
from bombgame.utils import FatalError, EventSource, log_errors
from bombgame.web.server import WebInterface, initialize_web_ui

LOGGER = getLogger("BombGame")


def initialize_can() -> can.BusABC:
    getLogger("CANBus").info("Initializing CAN bus")
    return can.Bus(**CAN_CONFIG)


def handle_fatal_error(error):
    LOGGER.fatal("Fatal error: %s", error)
    # TODO display a big failure in the UI


class BombGameController(EventSource):
    can_bus: Optional[can.BusABC]
    gpio: Optional[AbstractGpio]
    sound_system: Optional[BombSoundSystem]
    bus: Optional[BombBus]
    web_ui: Optional[WebInterface]
    room_server: Optional[RoomServerClient]
    dmx: Optional[DMXController]
    bomb: Optional[Bomb]
    _bomb_init_task: Optional[Task]

    def __init__(self, can_bus: Optional[can.BusABC] = None, gpio: Optional[AbstractGpio] = None):
        super().__init__()
        self.can_bus = can_bus
        self.gpio = gpio
        self.sound_system = None
        self.room_server = None
        self.bus = None
        self.web_ui = None
        self.dmx = None
        self.bomb = None
        self._bomb_init_task = None

    async def _initialize_bomb(self):
        self.bomb = Bomb(self.bus, self.gpio, self.sound_system, BOMB_CASING)
        self.trigger(BombChanged(self.bomb))
        self._bomb_init_task = create_task(self.bomb.initialize())
        await self._bomb_init_task
        self._bomb_init_task = None

    def _deinitialize_bomb(self):
        if self._bomb_init_task:
            self._bomb_init_task.cancel()
        self._bomb_init_task = None
        if self.bomb:
            self.bomb.deinitialize()

    async def start(self):
        LOGGER.info("Loading modules")
        load_modules()
        if self.can_bus is None:
            self.can_bus = initialize_can()
        if self.gpio is None:
            self.gpio = Gpio(BOMB_CASING)
            self.gpio.start()
        if ROOM_SERVER is not None:
            self.room_server = RoomServerClient()
            await self.room_server.start()
        self.sound_system = BombSoundSystem(self.room_server)
        await self.sound_system.start()
        self.bus = BombBus(self.can_bus)
        self.bus.add_listener(FatalError, handle_fatal_error)
        self.bus.start()
        self.web_ui = await initialize_web_ui(self)
        self.dmx = await initialize_bomb_dmx(self)
        create_task(log_errors(self._initialize_bomb()))

    async def stop(self):
        self._deinitialize_bomb()
        if self.dmx is not None:
            await self.dmx.stop()
        await self.web_ui.stop()
        self.bus.stop()
        if self.sound_system is not None:
            self.sound_system.stop()  # TODO wrap in executor?
        if self.room_server is not None:
            await self.room_server.stop()
        if self.gpio is not None:
            self.gpio.stop()  # TODO wrap in executor?
        if self.can_bus is not None:
            self.can_bus.shutdown()

    def reset(self):
        self._deinitialize_bomb()
        create_task(log_errors(self._initialize_bomb()))

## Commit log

2019-10-07 Initial project commit.
    [backplane.kicad_pcb, backplane.sch, korttipohja.kicad_pcb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]
2019-10-07 Iter 2019-10-07
    [backplane.sch]
2019-10-08 Refactor PCB files from root folder -> hardware/
    [backplane.kicad_pcb, backplane.sch, korttipohja.kicad_pcb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]
2019-10-26 Minor fixes to code style
    [bus.py, utils.py]
2019-10-28 Finish backplane release candidate.
    [backplane.kicad_pcb, backplane.sch]
2019-10-28 Add root PCB for module design.
    [korttipohja.sch]
2019-10-28 Add initialization sequence, timer module, some refactoring
2019-11-04 Add interrupt support to GPIO
2019-11-04 Properly implement Wires, Keypad, Simon Says and Timer
2019-11-06 Backplane mid term checkup revision.
    [backplane.kicad_pcb]
2019-11-08 Reorient RJ45 connectors in backplane, make interrupt pins accessible in IO Expanders
    [backplane.kicad_pcb, backplane.sch]
2019-11-11 Finish first iteration of module common backplane
    [korttipohja.kicad_pcb, korttipohja.sch]
2019-11-12 Start web UI, rewrite most events, fix Simon solution
    [config.py, controller.py, events.py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]
2019-11-18 Add +5V and +12V to module funcitonal PCB.
    [korttipohja.kicad_pcb, korttipohja.sch]
2019-11-18 Add keepout removig unnecessary small ground plane.
    [korttipohja.kicad_pcb]
2019-11-20 Add FETs for increased current control.
    [korttipohja.kicad_pcb, korttipohja.sch]
2019-12-02 Implement missing messages and crash simulation in Mock
    [mock.py]
2019-12-02 Add timer adapter pcb
    [backplane-B_Cu.gbr, backplane-B_Mask.gbr, backplane-B_Paste.gbr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]
2019-12-05 Add missing awaits to mock code
    [mock.py]
2019-12-06 Add logging, move configs to config.py, minor fixes
    [audio.py, bus.py, config.py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]
2019-12-07 Fix debug shell feature
    [controller.py, shell.py]
2019-12-07 Change all imports to absolute, fix code style in lots of places
    [audio.py, bus.py, config.py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]
2019-12-07 Add __repr__s to classes, fix some bugs, improve config.py
    [casings.py, config.py, controller.py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]
2019-12-07 Add start of web UI, fix LOTS OF BUGS so it actually works
    [bus.py, config.py, controller.py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]
2019-12-07 Add password module pcb
    [password.kicad_pcb, password.sch]
2019-12-07 Add copper fills
    [password.kicad_pcb]
2019-12-09 Fix VanillaCasing capacity
2019-12-09 Fix brainfart in GPIO
    [gpio.py]
2019-12-09 Realize that MCP23017 does not invert outputs
    [gpio.py]
2019-12-09 Reduce noise in log
    [controller.py]
2019-12-09 Fix bugs with __members__ and add timer speed-up
2020-04-25 Working sound, fixed Simon, rewritten Wires, bomb serial in web, better logging, lots of nasty bugfixes
    [audio.py, config.py, controller.py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]
2020-04-25 Add current version of module Arduino files
2020-04-25 Fix timer module display calculations
    [timer.cpp]
2020-04-30 Clean up prototyping/base module, change to current rj45 connector type
    [korttipohja.kicad_pcb, korttipohja.sch, module_base.kicad_pcb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]
2020-04-30 Recreate timer module with single PCB, clean up libraries
    [module_base.kicad_pcb, module_base.sch, module_shared.sch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]
2020-05-01 Redo prototyping module layout: CAN module on back, two rows of pins
    [module_base.kicad_pcb, module_base.sch]
2020-05-02 Remove strikes after explosion for Wires
2020-05-02 Fix audio distortion by making all sounds quieter
    [audio.py]
2020-05-05 New backplane schematic
    [backplane.kicad_pcb, backplane.sch]
2020-05-05 First revision of PCB layout for backplane v2
    [backplane.kicad_pcb, backplane.sch]
2020-09-24 Timer PCB: use non-LED RJ45, update layout, reroute
    [module_shared.sch, timer.kicad_pcb, timer.sch]
2020-09-25 Create single-board Password PCB
    [module_shared.sch, password.kicad_pcb, password.sch]
2020-09-25 Password PCB: spread letters apart and reroute
    [password.kicad_pcb]
2020-09-25 Password PCB: switch to correct RGB LED symbol
    [password.kicad_pcb, password.sch]
2020-09-25 Add Keypad PCB
    [keypad.kicad_pcb, keypad.sch, module_shared.sch]
2020-09-25 Timer PCB: add copper fills
    [timer.kicad_pcb]
2020-09-25 Timer PCB: reduce copper fill clearance
    [timer.kicad_pcb]
2020-09-25 ModuleBase PCB: change RJ45 jack, add mounting holes, reorganize
    [module_base.kicad_pcb, module_shared.sch]
2020-09-26 Backplane PCB: add audio filter circuit
    [backplane.kicad_pcb, backplane.sch]
2020-09-29 Keypad PCB: add debouncing caps
    [keypad.kicad_pcb, keypad.sch]
2020-10-06 Backplane PCB: add overvoltage protection, remove some 0Rs, some reorganization
    [backplane.kicad_pcb, backplane.sch]
2020-10-06 Backplane PCB: some rerouting to avoid vias in I2C/CAN
    [backplane.kicad_pcb]
2020-10-06 Backplane PCB: remove 3.3V from backplane connector
    [backplane.kicad_pcb, backplane.sch]
2020-10-06 Backplane PCB: thermal pads for power FETs, lots of finishing touches
    [backplane.kicad_pcb, backplane.sch]
2020-10-08 Clean up symbol libraries, delete outdated files
    [backplane-B_Cu.gbr, backplane-B_Mask.gbr, backplane-B_Paste.gbr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]
2020-10-10 Backplane PCB: add section field to components
    [backplane.sch]
2020-10-11 Add missing copper fills and edge cuts
    [module_base.kicad_pcb, password.kicad_pcb]
2020-10-18 Backplane PCB: clean up power input, widen a trace
    [backplane.kicad_pcb]
2020-10-28 Timer PCB: fix mounting hole location
    [timer.kicad_pcb]
2020-10-28 Add identifying silkscreen text, fix missing connections on ModuleBase
    [backplane.kicad_pcb, keypad.kicad_pcb, module_base.kicad_pcb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]
2020-11-04 ModuleBase PCB: add lots of mounting holes and some grounds
    [module_base.kicad_pcb, module_base.sch]
2020-11-04 Backplane PCB: add THICC power traces, rotate silkscreen text the same way
    [backplane.kicad_pcb]
2020-11-06 Password PCB: change display polarity
    [module_shared.sch, password.kicad_pcb, password.sch]
2020-11-06 Timer PCB: fix kicad router brain fart
    [timer.kicad_pcb]
2020-11-07 Keypad PCB: add holes for PCB-mounted switches
    [keypad.kicad_pcb, keypad.sch]
2020-11-19 Add MODULE_READY and new timer board to firmware
2020-12-01 Password PCB: swap ADC-only pin A6 for A5
    [password.kicad_pcb, password.sch]
2020-12-02 ModuleBase PCB: expose Arduino pins + SPI + more GND/5V
    [module_base.kicad_pcb, module_base.sch, module_shared.sch]
2020-12-03 ModuleBase PCB: longer pads for HT1632C footprint
    [module_base.kicad_pcb, module_base.sch]
2020-12-05 Avoid using D10 (SPI SS) pin as input
    [keypad.kicad_pcb, keypad.sch, password.kicad_pcb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]
2020-12-05 Firmware fixes for Password
    [module.h, password.cpp, password.h]
2020-12-05 Fix Timer strike pin polarity
    [timer.cpp]
2020-12-05 Update Button firmware to use WS2812B
2020-12-05 Minor bugfixes and refactors
    [gpio.py, mock.py, module.h]
2020-12-06 Add Button support to main controller
2020-12-06 Update Wires support to latest version
2020-12-06 Fix bugs and separate main methods
    [__main__.py, audio.py, controller.py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]
2020-12-06 Update Wires & Complicated Wires firmware
2020-12-06 Avoid some gcc warnings
    [module.ino]
2020-12-06 Bugfixes to main controller
    [audio.py]
2020-12-06 Correct Wires pin order, add support for red+blue wires, re-send state after reset
    [wires.cpp, wires.h]
2020-12-07 Add main controller for Complicated Wires, improve messages
2020-12-07 Fix Complicated Wires LEDs
    [wires.cpp, wires.h]
2020-12-07 Add web UI button for starting timer
2020-12-07 Fix bugs in Keypad and Wires
2020-12-08 Add note about voltages in adding_modules.md
2020-12-10 Keypad PCB: fix switch positions
    [keypad.kicad_pcb]
2020-12-10 Backplane PCB: I2S audio and complete relayout
    [backplane.kicad_pcb, backplane.sch]
2022-02-13 Fix bugs in main controller
    [controller.py, dmx.py]
2022-02-14 Add Venting Gas and bugfixes
    [casings.py, dmx.py, events.py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]
2022-08-14 Add new backplane and serial number widget
    [backplane.kicad_pcb, backplane.kicad_sch, backplane.sch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]
2022-10-07 Bugfix Venting Gas, update (Comp)Wires solutions based on state
